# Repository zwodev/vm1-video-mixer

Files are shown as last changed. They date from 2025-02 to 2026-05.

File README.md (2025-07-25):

# VM-1 / The Video Mixer for Everyone

The VM-1 is an open-source hardware project for live mixing of videos, camera images and generative graphics. It is based on the widely used and affordable Raspberry Pi (5) platform, allowing creative media projects of all sorts.

Learn more about the VM-1 on our website: [VM-1 Website](https://vm-1.com)

## 🚀 Quick Start

You want to build your very own VM-1?! Awesome! This is how you do it:

### 1. Order the Parts
You're lucky! We've prepared a shopping list for you. This is a link to the shopping cart at BerryBase (Berlin, Germany). You don't have to buy the parts there and this is no affiliate link. It's just for your convenience!
This list includes everything you need. If you already own some parts, just delete them from the cart.

[Shopping List](https://www.berrybase.de/loadBasket/sqdnehV_owC)

### 2. Print your Case
Don't worry, you do not have wildly connect all the parts. We've prepared a neat little housing for your VM-1. You just have to print it on your own, your friend's or your makerspace's 3D-printer. If you have trouble getting your case printed, don't worry and drop us a line.

[3D Printing Files](#)

### 3. Download VM-1 image and flash your SD card
TODO

### 4. Assemble the VM-1
TODO

### 5. First Steps
TODO

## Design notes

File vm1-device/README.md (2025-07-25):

# VM-1 Controller

`arduino` - firmware

`kicad`- pcb

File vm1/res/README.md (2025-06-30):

# Enable autostart of VM1 and LocalSend

1) Check if directory `~/.config/systemd/user/` exists. If not, create it.
2) Copy `vm1.service` and `localsend.service` to `~/.config/systemd/user/`
3) Enable vm1.service:

```
$ systemctl --user enable localsend.service
$ systemctl --user enable vm1.service
$ systemctl --user daemon-reload
```

4) Reboot Raspberry Pi

# Enable external antenna (on Compute Module only)

1) Add `dtparam=ant2` to `/boot/firmware/config.txt`
2) disable power management for wifi adapter with systemd on system level:

```
sudo nano /etc/systemd/system/wifi-power-save-off.service
```

content:

```
[Unit]
Description=Disable WiFi Power Saving
After=network.target

[Service]
Type=oneshot
ExecStart=/sbin/iwconfig wlan0 power off
RemainAfterExit=true

[Install]
WantedBy=multi-user.target

```

enable it with:

```
sudo systemctl daemon-reexec 
sudo systemctl enable wifi-power-save-off.service
sudo systemctl start wifi-power-save-off.service   # or reboot
```

3) Reboot Raspberry Pi

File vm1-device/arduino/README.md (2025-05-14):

# VM-1 Controller

## Installation of existing binaries

~~On the Raspberry Pi Pico (V1), press and hold the `bootsel` button while plugging in into your USB-Port. It will appear as a removable disk. Drag and Drop the file `bin/VM1_Keyboard.ino.uf2` onto it. The Pi Pico will reboot and show up as a keyboard on your computer. You can then use it with your VM-1.~~

--> t.b.a.

## Assignments

### Buttons
* The controller acts simply as a HID Keyboard
* left-most button is `KEY_LEFT_SHIFT`
* two buttons at the top-right are `KEY_ARROW_LEFT` and `KEY_ARROW_RIGHT`
* the 8x3 button matrix is:
	* `q` `w` `e` `r` `t` `y` `u` `i`
	* `a` `s` `d` `f` `g` `h` `j` `k`
	* `z` `x` `c` `v` `b` `n` `m` `,`

### Rotary Encoder
* Acts as `ARROW_DOWN` (turn CW) and `ARROW_UP` (turn CCW)

### LEDs

* The four LEDs blink in a row. 
* ~~ You can change them with *Serial Commands*:~~
	* `0` - start the running animation (default)
	* `1` - turn on LED 1
	* `2` - turn on LED 2
	* `3` - turn on LED 3
	* `4` - turn on LED 4

## Working on the project

If you want to extend the VM-1 keyboard, you can use that with the source-code found in the `VM1_Keyboard`-folder. We use the PiPico board library by [Earle Philhower](https://github.com/earlephilhower/arduino-pico?tab=readme-ov-file#installation) because the implementation of the HID-Keyboard worked better for us. Please follow the installation instructions in the link (adding the link to the board-library in the Arduino-Settings). 

#### Used Libraries

In Arduino IDE, choose `Raspberry Pi Pico` (*not the Arduino Mbed, but the one mentioned above!*) as your Board. The following libraries are used:

* ~~[https://github.com/gbr1/rp2040-encoder-library](https://github.com/gbr1/rp2040-encoder-library)~~
	* this library gets in conflict with the Adafruit NeoPixels library. 

# Installing Arduino CLI on your Raspberry Pi

I attached the PiPico (aka the VM-1 Keyboard) to the Raspberry Pi (aka the VM-1). It shall be programmed directly from there.

The PiPico shows up as serial device under `/dev/ttyACM0`

In the home directory:

```
curl -fsSL https://raw.githubusercontent.com/arduino/arduino-cli/master/install.sh | sh
export PATH=$PATH:$HOME/bin

arduino-cli config init
arduino-cli config set board_manager.additional_urls https://github.com/earlephilhower/arduino-pico/releases/download/global/package_rp2040_index.json
arduino-cli core update-index
arduino-cli core install rp2040:rp2040

```

In the arduino project directory (`/home/vm1/Documents/coding/vm1-video-mixer/vm1-controller/arduino/VM1_Keyboard`) you can compile it with

arduino-cli compile --fqbn rp2040:rp2040:rpipico --verbose --build-path ./build .

### ~~not needed (hopefully) BEGIN~~
~~upload the file to pi pico~~
~~press bootsel button and plug the pico in~~
~~(mount if needed)~~
~~mkdir -p ~/pico_mount~~
~~lsblk~~
~~sudo mount /dev/sda1 ~/pico_mount~~

~~sudo cp your_program.uf2 ~/pico_mount/~~
### ~~not needed END~~

# get a serial monitor

sudo apt-get install minicom

minicom -b 115200 -o -D /dev/ttyACM0

# Install Neopixel library

arduino-cli lib install "Adafruit NeoPixel"

# Install MessagePack

git clone https://github.com/hideakitai/MsgPack.git
git clone https://github.com/hideakitai/DebugLog.git
git clone https://github.com/hideakitai/ArxTypeTraits.git
git clone https://github.com/hideakitai/ArxContainer.git

# install Rotary Encoder Library

git clone https://github.com/tobiglaser/RP2040-Encoder.git

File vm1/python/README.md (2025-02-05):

# HOWTO

## Install dependencies on Raspberry Pi 4/5
```
# gstreamer
sudo apt install libgstreamer1.0-dev libgstreamer-plugins-base1.0-dev libgstreamer-plugins-bad1.0-dev gstreamer1.0-plugins-ugly gstreamer1.0-tools gstreamer1.0-gl gstreamer1.0-gtk3 python3-gst-1.0

```

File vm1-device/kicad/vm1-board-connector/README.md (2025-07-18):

# VM1 Board Connector

Connects the VM1-Device PCB with the Raspberry Pi CM5 IO Board PCB.

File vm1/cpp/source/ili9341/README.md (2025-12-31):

# ILI9341 Display Driver

This directory contains the driver for the 2.8-inch ILI9341 SPI LCD display.

## Pin Connections

The driver uses the following GPIO pins (BCM numbering):

- **CS (Chip Select)**: GPIO 7
- **RST (Reset)**: GPIO 17  
- **RS/DC (Register Select/Data Command)**: GPIO 22
- **LED (Backlight)**: GPIO 18
- **MOSI**: SPI0 MOSI (GPIO 10)
- **SCK**: SPI0 SCK (GPIO 11)
- **MISO**: SPI0 MISO (GPIO 9) - optional, not used for display writes

## Hardware Setup

1. Connect the display to the Raspberry Pi according to the pin mapping above
2. The display uses SPI bus 0 (same as OLED, but different CS pin)
3. Power: Connect VCC to 5V and GND to ground

## Usage

The `ILI9341Controller` class provides a high-level interface similar to `OledController`:

```cpp
#include "ILI9341Controller.h"

ILI9341Controller display;
display.setStbRenderer(stbRenderer);  // Optional: for rendering UI
display.start();  // Start the display thread
// ... use display ...
display.stop();   // Stop when done
```

## Display Specifications

- **Resolution**: 240x320 pixels
- **Color Format**: RGB565 (16-bit color)
- **SPI Mode**: Mode 0
- **SPI Speed**: 32 MHz

## Notes

- The display driver uses **weak linkage** to avoid conflicts with the OLED driver
- Both displays can coexist on the same SPI bus using different CS pins
- The display will NOT be used as the main system display - it's a pure SPI device
- Touch functionality is not implemented (as requested)

## Integration

To use the ILI9341 display in your application, you can:

1. Create an instance of `ILI9341Controller`
2. Optionally connect it to a `StbRenderer` for UI rendering
3. Call `start()` to begin displaying content
4. The display will automatically update from the renderer

Example integration in `VM1Application`:

```cpp
ILI9341Controller m_ili9341Display;

// In initialization:
m_ili9341Display.setStbRenderer(&m_stbRenderer);
m_ili9341Display.start();
```

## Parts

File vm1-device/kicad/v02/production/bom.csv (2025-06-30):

Designator | Footprint | Quantity | Value | LCSC Part #
3.3V1 | TestPoint_Pad_2.0x2.0mm | 1 | 3.3V
ADC_0 | TestPoint_Pad_2.0x2.0mm | 1 | ADC_0
ADC_1 | TestPoint_Pad_2.0x2.0mm | 1 | ADC_1
ADC_2 | TestPoint_Pad_2.0x2.0mm | 1 | ADC_2
ADC_3 | TestPoint_Pad_2.0x2.0mm | 1 | ADC_3
C1, C2, C3, C4 | 0402 | 4 | 10n | C15195
C10, C23, C24, C8 | 0402 | 4 | 1u | C52923
C11, C12, C13, C14, C15, C16, C22, C25, C5, C6, C7, C9 | 0402 | 12 | 100n
C17, C18 | 0402 | 2 | 15p
C19, C20, C21 | CP_EIA-3216-10_Kemet-I | 3 | 10u | C7171
D1, D10, D11, D12, D13, D14, D15, D16, D17, D18, D19, D2, D20, D21, D22, D23, D24, D25, D26, D27, D28, D29, D3, D30, D31, D32, D33, D4, D5, D6, D7, D8, D9 | LED_WS2812B-2020_PLCC4_2.0x2.0mm | 33 | WS2812B-2020
GND1 | TestPoint_Pad_2.0x2.0mm | 1 | GND
H1, H2, H22, H3, H4, H5 | MountingHole_3.2mm_M3 | 6 | MountingHole
R1, R10, R11, R18, R2, R20, R21, R22, R3, R4, R5, R6, R7, R8, R9 | 0402 | 15 | 10k | C25744
R12, R13, R23 | 0402 | 3 | 27
R15, R16 | 0402 | 2 | 1k
R17, R19 | 0402 | 2 | 5.1k
U1, U10, U11, U12, U13, U14, U15, U16, U17, U18, U19, U2, U20, U21, U22, U23, U24, U25, U26, U28, U3, U4, U5, U6, U7, U8, U9 | D_SOD-123 | 27 | 1N4148W_C81598 | C81598
U27 | SOT-353_L2.1-W1.3-P0.65-LS2.3-BR | 1 | 74LVC1G17GW,125_C426705 | C426705
U29 | SOT-223-3_L6.5-W3.4-P2.30-LS7.0-BR | 1 | AMS1117-3_3 | C6186
U30 | RP2040-QFN-56 | 1 | RP2040 | C2040
U31 | USB-C-SMD_TYPE-C-6PIN-2MD-073 | 1 | TYPE-C_16PIN_2MD(073) | C2765186
U32 | SOIC-8_L5.3-W5.3-P1.27-LS8.0-BL | 1 | W25Q128JVSIQTR | C97521
U33, U34 | SW-SMD_L3.9-W3.0-P4.45 | 2 | TS-1088-AR02016 | C720477
X2 | CRYSTAL-SMD_4P-L3.2-W2.5-BL | 1 | ABM8-272-T3_C20625731 | C20625731

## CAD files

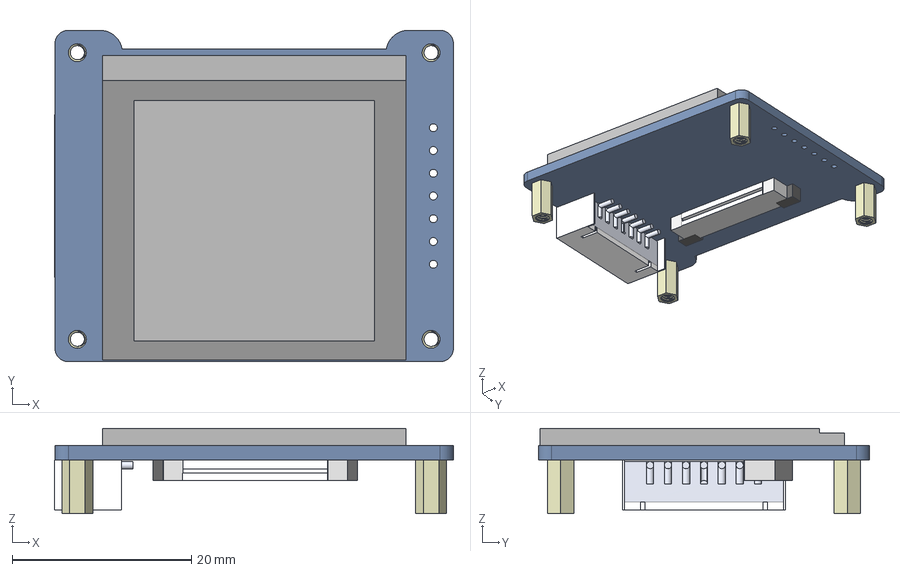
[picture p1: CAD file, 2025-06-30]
vm1-device/kicad/v02/3dmodels/1_5inch-rgb-oled-module_asm-1110.stp
44.5 x 37.0 x 9.50 mm
1_5INCH-RGB-OLED
1_5INCH_OLED_RGB_PCBA
M2XH6_COPPER-POST x 4

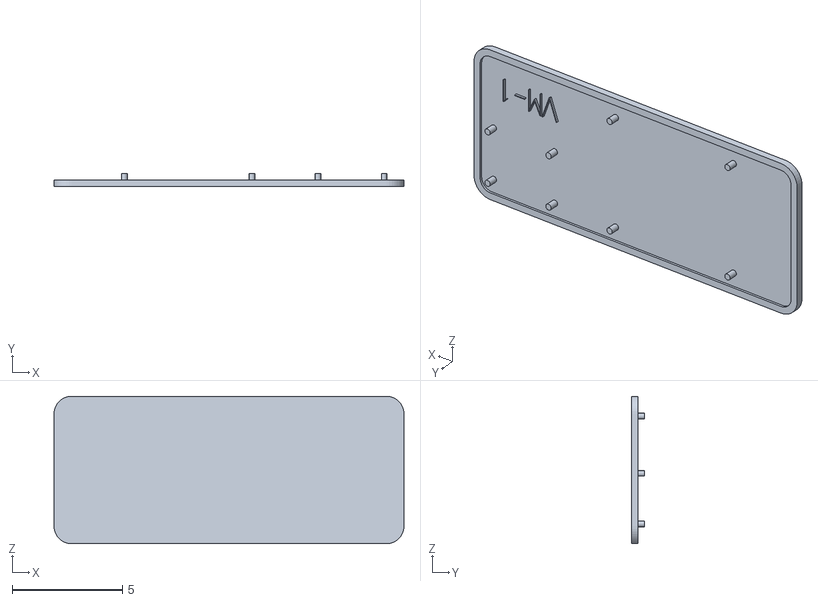
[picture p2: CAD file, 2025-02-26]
3d-print/prototype/baseplate.stl
15.9 x 0.6 x 6.70

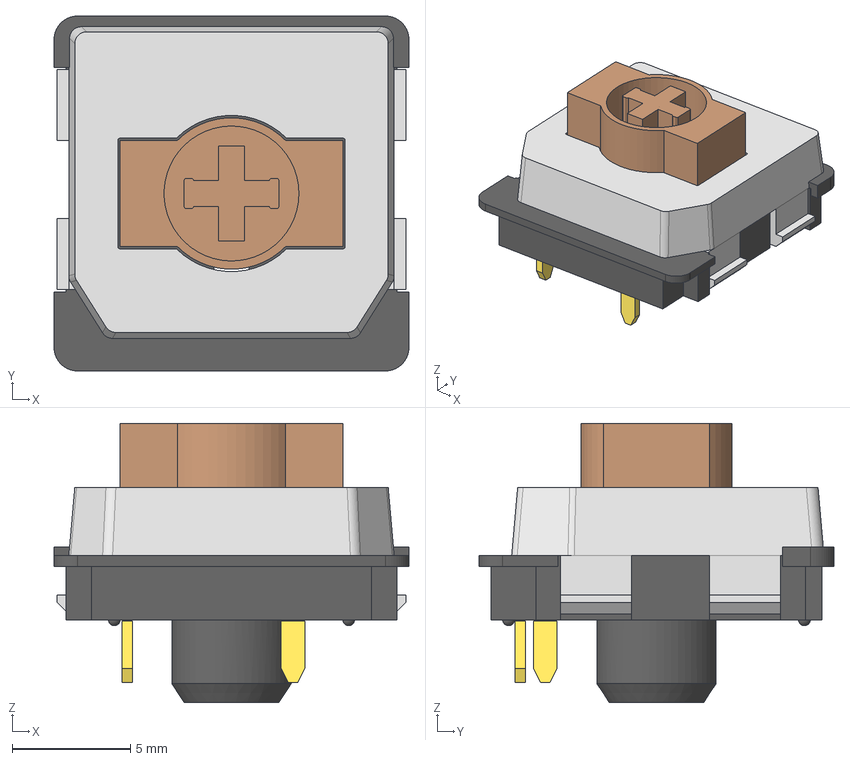
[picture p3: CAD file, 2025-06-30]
vm1-device/kicad/v02/3dmodels/ks33.step
15.0 x 15.0 x 11.8 mm
f0684a6a-028c-11ee-ae0e-34c93d8226b1_part
f06a1f0c-028c-11ee-ae0e-34c93d8226b1_part
f1cc5b76-028c-11ee-ae0e-34c93d8226b1_part
f1cc5d06-028c-11ee-ae0e-34c93d8226b1_part
f1cc5d92-028c-11ee-ae0e-34c93d8226b1_part

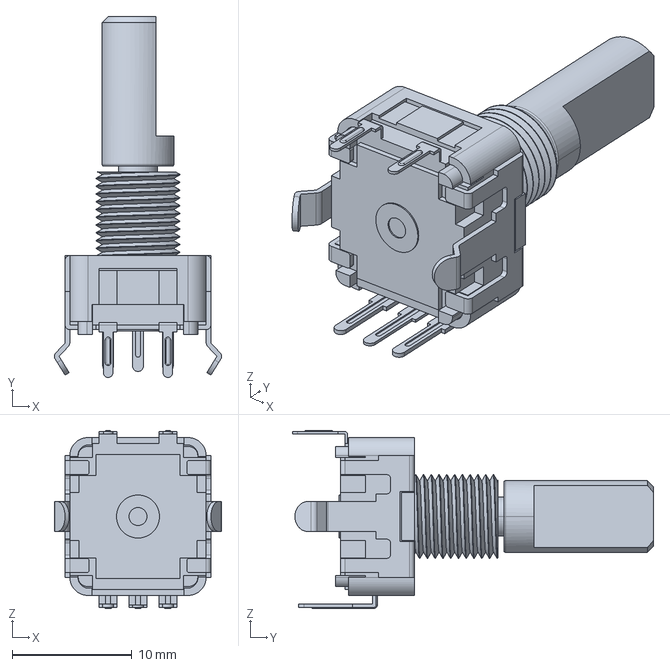
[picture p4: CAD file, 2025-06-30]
vm1-device/kicad/v02/3dmodels/7377754.stp
14.0 x 30.2 x 14.9 mm

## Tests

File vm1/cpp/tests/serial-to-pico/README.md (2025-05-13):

# Test for sending a MessagePack message

...which will be received by [this Arduino script](https://github.com/zwodev/vm1-video-mixer/tree/master/vm1-controller/arduino/tests/20250507-msgpck-receive-and-neopixels-test).

## Dependencies

```
$ sudo apt install libmsgpack-dev
```
## Compile and Run
```
$ mkdir builddir
$ meson setup builddir

$ meson compile -C builddir
$ ./builddir/serial-test
```

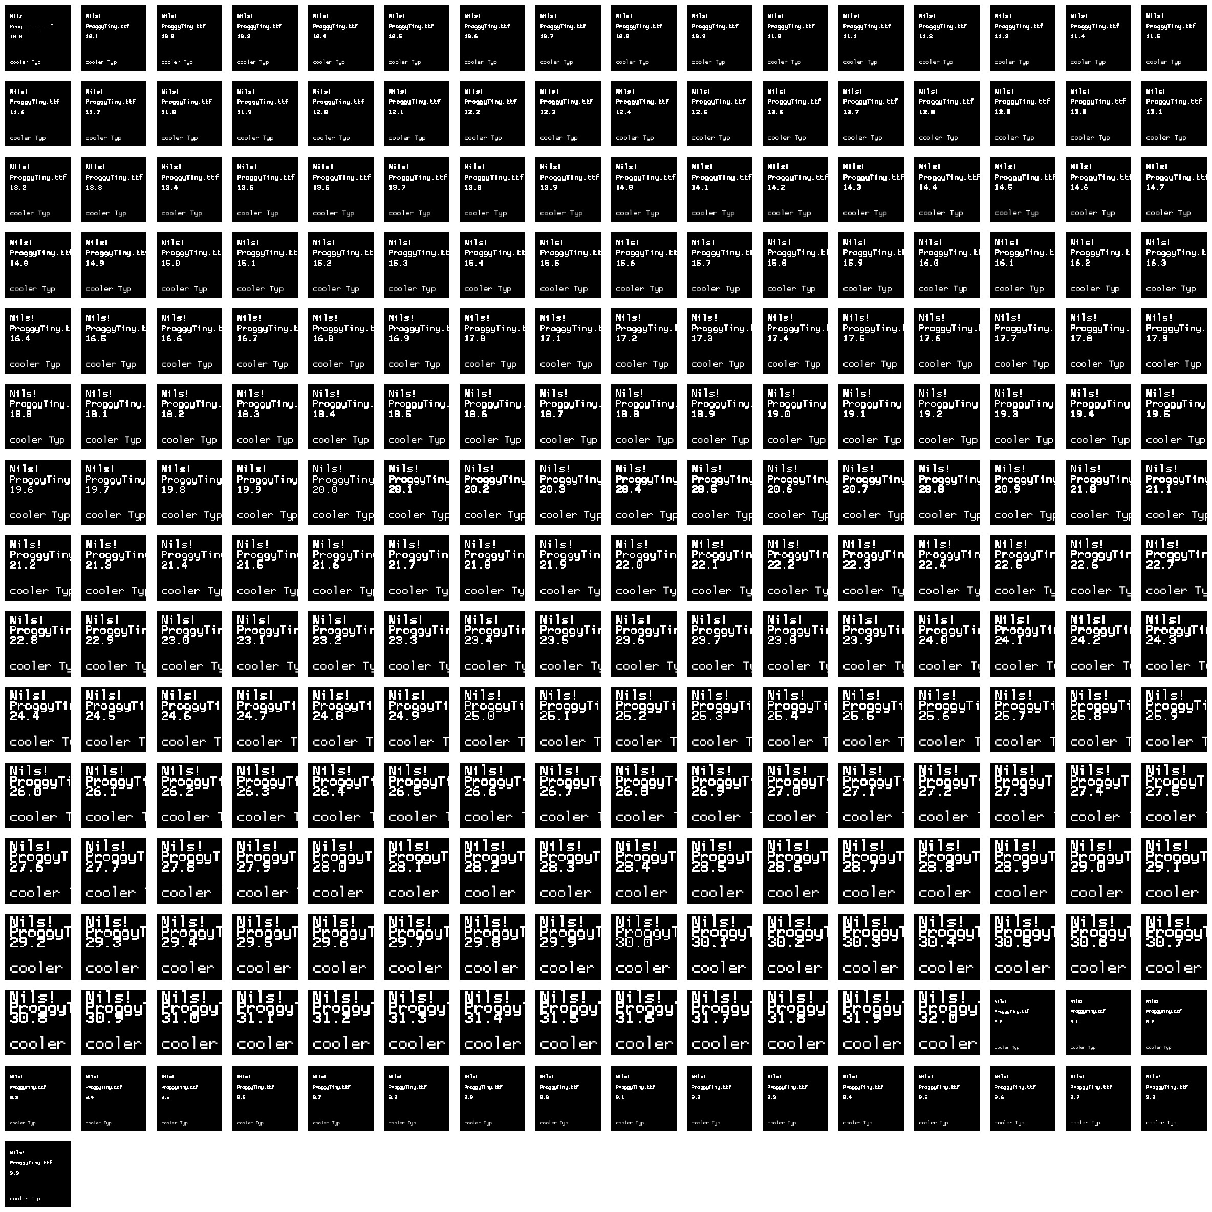
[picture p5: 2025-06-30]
vm1/cpp/tests/stb-test/rendered-tiles/ProggyTiny.png

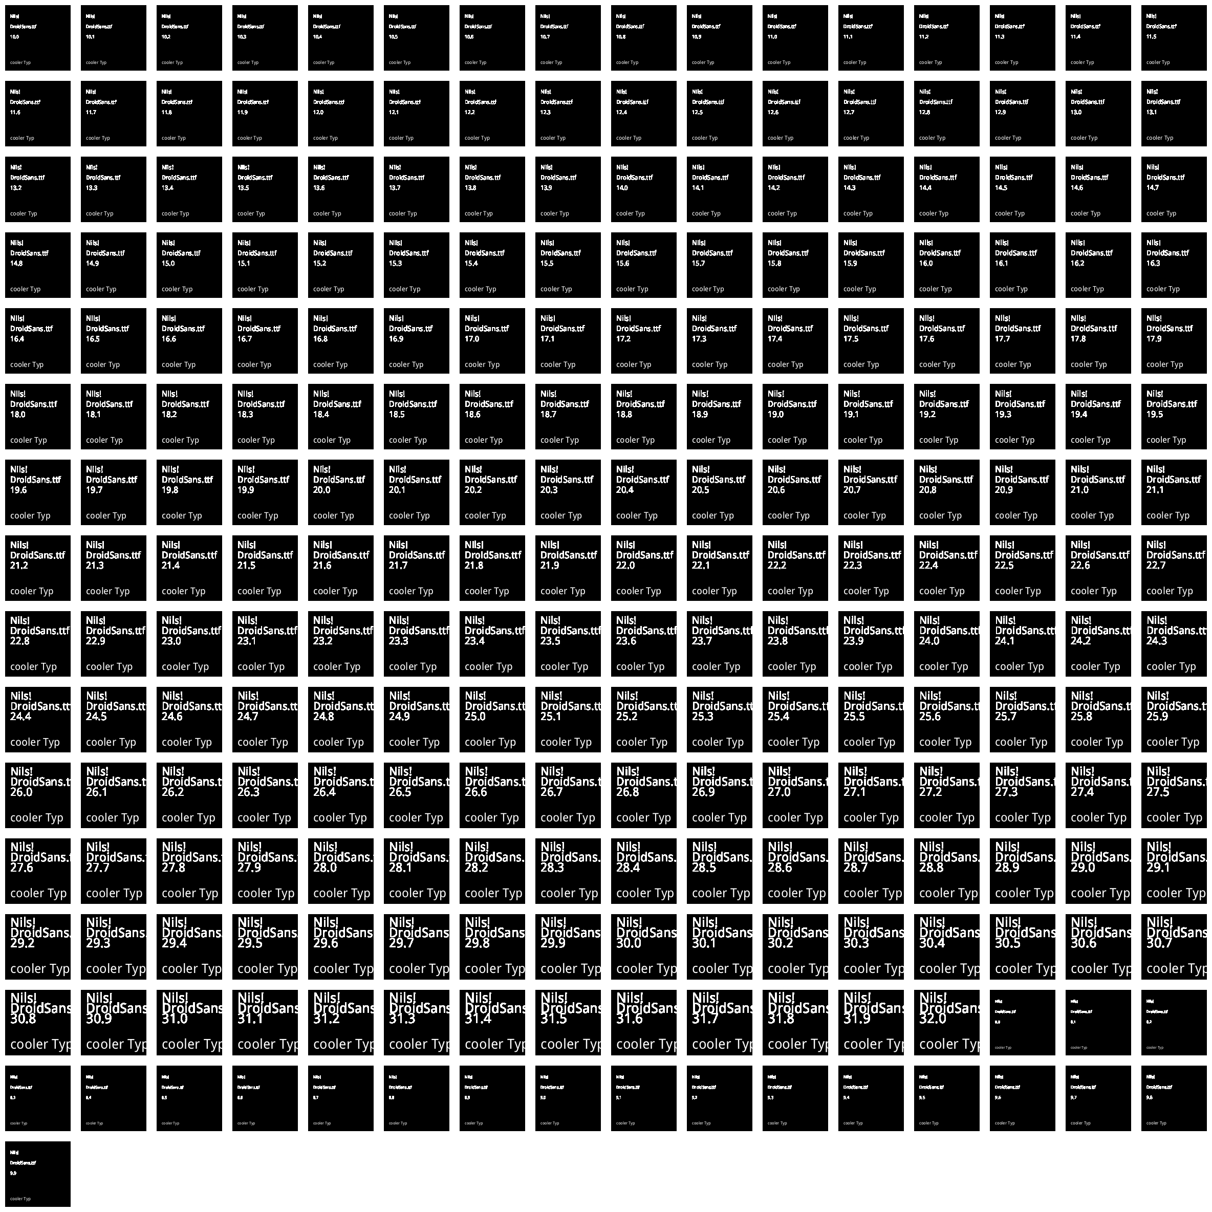
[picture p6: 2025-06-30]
vm1/cpp/tests/stb-test/rendered-tiles/DroidSans.png

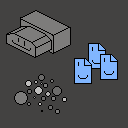
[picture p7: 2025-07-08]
vm1/cpp/tests/stb-test/resources/source-file.png

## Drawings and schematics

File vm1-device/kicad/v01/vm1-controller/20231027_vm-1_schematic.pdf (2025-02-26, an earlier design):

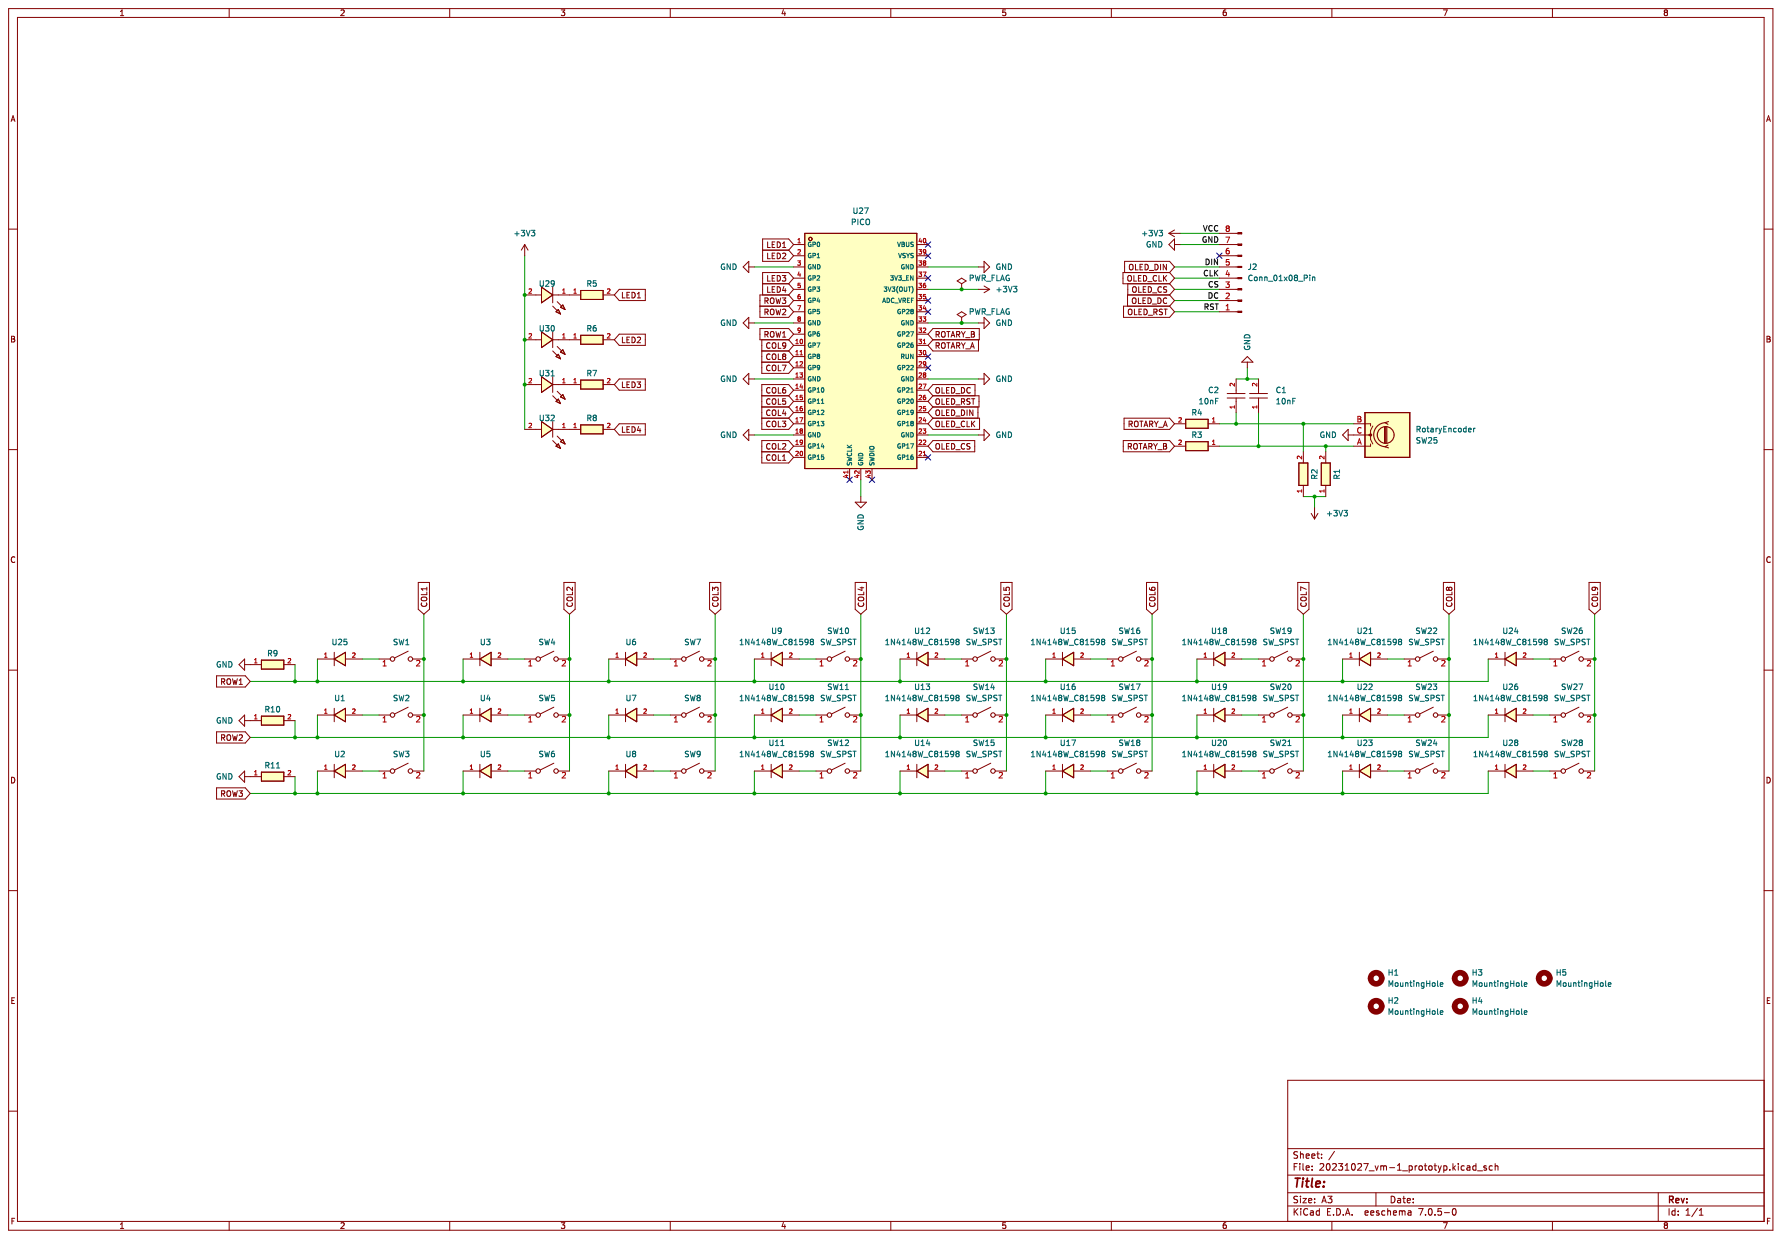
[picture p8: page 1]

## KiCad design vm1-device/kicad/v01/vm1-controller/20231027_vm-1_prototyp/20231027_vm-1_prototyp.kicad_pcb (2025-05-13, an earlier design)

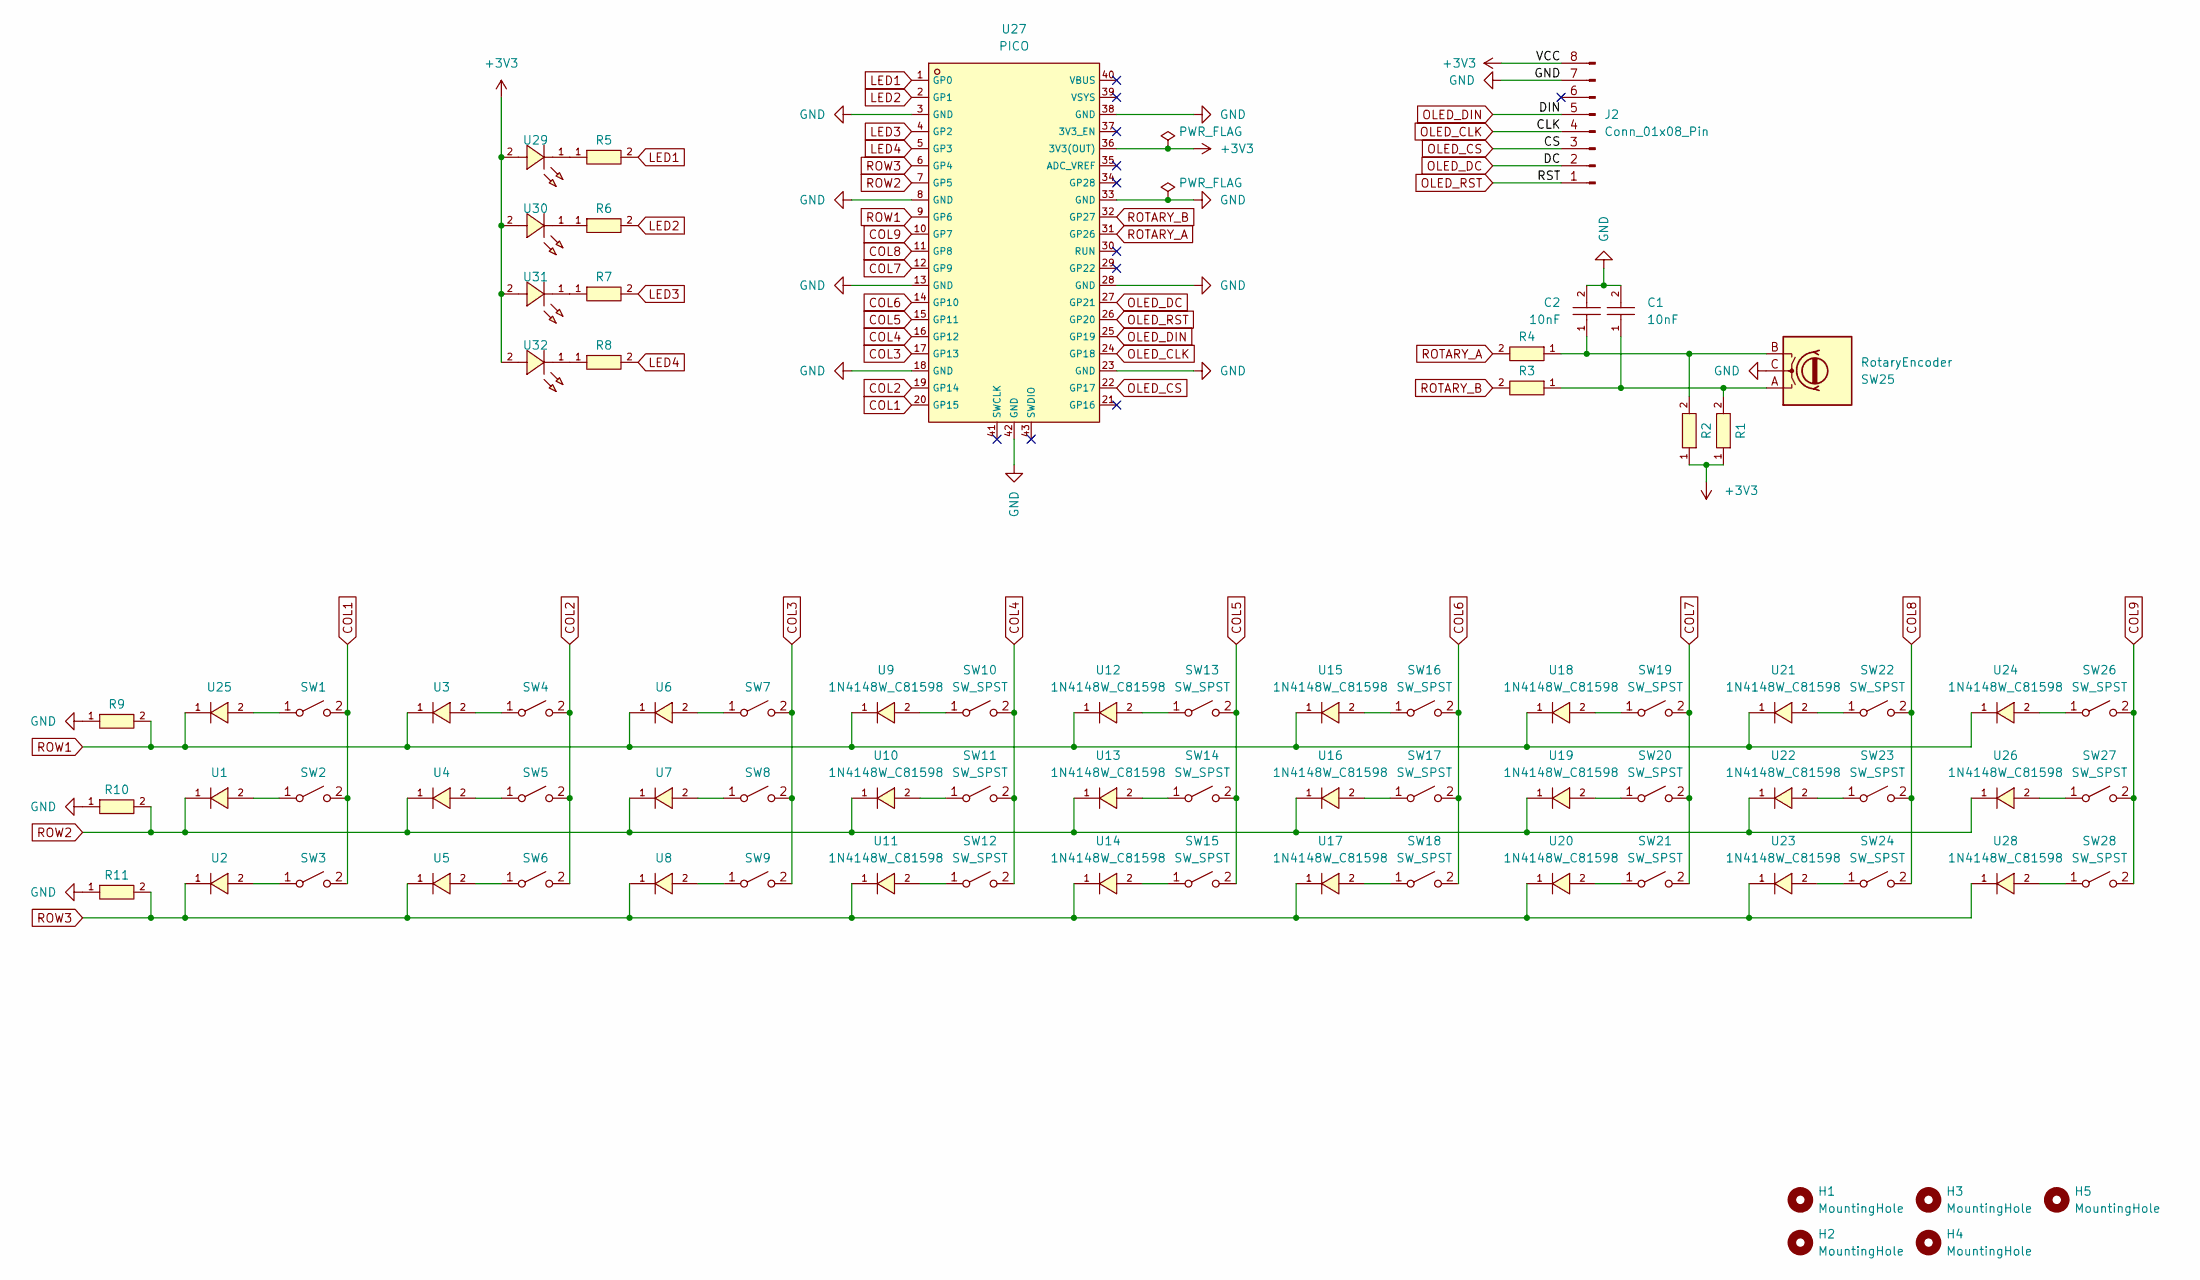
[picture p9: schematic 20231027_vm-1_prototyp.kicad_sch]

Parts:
C1, C2: 10nF; C0402; LCSC C15195
H1, H2, H3, H4, H5: MountingHole; MountingHole_3.2mm_M3
J2: Conn_01x08_Pin; Waveshare OLED 1.5in
R1, R2, R9, R10, R11: 0402WGF1002TCE; R0402; LCSC C25744
R3, R4: 0402WGF1002TCE 10k; R0402; LCSC C25744
R5, R6, R7, R8: 0402WGF1000TCE; R0402; LCSC C25076
SW1, SW2, SW3, SW4, SW5, SW6, SW7, SW8, SW9, SW10, SW11, SW12, SW13, SW14, SW15, SW16, SW17, SW18, SW19, SW20, SW21, SW22, SW23, SW24, SW26, SW27, SW28: SW_SPST; SW_Cherry_MX_PCB_1.00u
SW25: RotaryEncoder; RotaryEncoder_Bourns_Vertical_PEC12R-3xxxF-Nxxxx
U1, U2, U3, U4, U5, U6, U7, U8, U9, U10, U11, U12, U13, U14, U15, U16, U17, U18, U19, U20, U21, U22, U23, U24, U25, U26, U28: 1N4148W_C81598; SOD-123F_L2.7-W1.6-LS3.8-RD; LCSC C81598
U27: PICO; COMM-SMD_L51.0-W21.0-P2.54_SC0916; LCSC C7203002
U29, U30, U31, U32: 95-21SURC_S530-A3_TR10; LED-SMD_L2.1-W2.0-RD; LCSC C2936535

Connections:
+3V3: J2.8, R1.1, R2.1, U27.36 (3V3(OUT)), U29.2 (A), U30.2 (A), U31.2 (A), U32.2 (A)
COL1: SW1.2 (B), SW2.2 (B), SW3.2 (B), U27.20 (GP15)
COL2: SW4.2 (B), SW5.2 (B), SW6.2 (B), U27.19 (GP14)
COL3: SW7.2 (B), SW8.2 (B), SW9.2 (B), U27.17 (GP13)
COL4: SW10.2 (B), SW11.2 (B), SW12.2 (B), U27.16 (GP12)
COL5: SW13.2 (B), SW14.2 (B), SW15.2 (B), U27.15 (GP11)
COL6: SW16.2 (B), SW17.2 (B), SW18.2 (B), U27.14 (GP10)
COL7: SW19.2 (B), SW20.2 (B), SW21.2 (B), U27.12 (GP9)
COL8: SW22.2 (B), SW23.2 (B), SW24.2 (B), U27.11 (GP8)
COL9: SW26.2 (B), SW27.2 (B), SW28.2 (B), U27.10 (GP7)
GND: C1.2, C2.2, J2.7, R9.1, R10.1, R11.1, SW25.C, U27.3 (GND), U27.8 (GND), U27.13 (GND), U27.18 (GND), U27.23 (GND), U27.28 (GND), U27.33 (GND), U27.38 (GND), U27.42 (GND)
LED1: R5.2, U27.1 (GP0)
LED2: R6.2, U27.2 (GP1)
LED3: R7.2, U27.4 (GP2)
LED4: R8.2, U27.5 (GP3)
unnamed: C1.1, R1.2, R3.1, SW25.A
unnamed: C2.1, R2.2, R4.1, SW25.B
unnamed: SW1.1 (A), U25.2 (A)
unnamed: SW2.1 (A), U1.2 (A)
unnamed: SW3.1 (A), U2.2 (A)
unnamed: SW4.1 (A), U3.2 (A)
unnamed: SW5.1 (A), U4.2 (A)
unnamed: SW6.1 (A), U5.2 (A)
unnamed: SW7.1 (A), U6.2 (A)
unnamed: SW8.1 (A), U7.2 (A)
unnamed: SW9.1 (A), U8.2 (A)
unnamed: SW10.1 (A), U9.2 (A)
unnamed: SW11.1 (A), U10.2 (A)
unnamed: SW12.1 (A), U11.2 (A)
unnamed: SW13.1 (A), U12.2 (A)
unnamed: SW14.1 (A), U13.2 (A)
unnamed: SW15.1 (A), U14.2 (A)
unnamed: SW16.1 (A), U15.2 (A)
unnamed: SW17.1 (A), U16.2 (A)
unnamed: SW18.1 (A), U17.2 (A)
unnamed: SW19.1 (A), U18.2 (A)
unnamed: SW20.1 (A), U19.2 (A)
unnamed: SW21.1 (A), U20.2 (A)
unnamed: SW22.1 (A), U21.2 (A)
unnamed: SW23.1 (A), U22.2 (A)
unnamed: SW24.1 (A), U23.2 (A)
unnamed: SW26.1 (A), U24.2 (A)
unnamed: SW27.1 (A), U26.2 (A)
unnamed: SW28.1 (A), U28.2 (A)
unnamed: R5.1, U29.1 (K)
unnamed: R6.1, U30.1 (K)
unnamed: R7.1, U31.1 (K)
unnamed: R8.1, U32.1 (K)
OLED_CLK: J2.4, U27.24 (GP18)
OLED_CS: J2.3, U27.22 (GP17)
OLED_DC: J2.2, U27.27 (GP21)
OLED_DIN: J2.5, U27.25 (GP19)
OLED_RST: J2.1, U27.26 (GP20)
ROTARY_A: R4.2, U27.31 (GP26)
ROTARY_B: R3.2, U27.32 (GP27)
ROW1: R9.2, U3.1 (K), U6.1 (K), U9.1 (K), U12.1 (K), U15.1 (K), U18.1 (K), U21.1 (K), U24.1 (K), U25.1 (K), U27.9 (GP6)
ROW2: R10.2, U1.1 (K), U4.1 (K), U7.1 (K), U10.1 (K), U13.1 (K), U16.1 (K), U19.1 (K), U22.1 (K), U26.1 (K), U27.7 (GP5)
ROW3: R11.2, U2.1 (K), U5.1 (K), U8.1 (K), U11.1 (K), U14.1 (K), U17.1 (K), U20.1 (K), U23.1 (K), U27.6 (GP4), U28.1 (K)

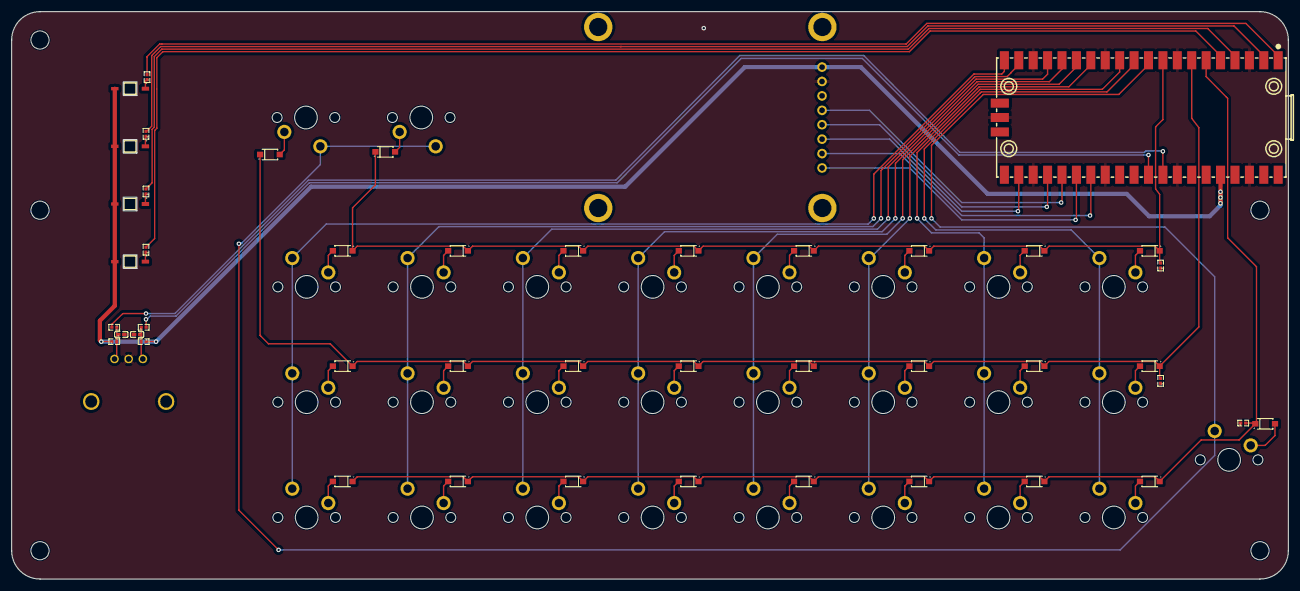
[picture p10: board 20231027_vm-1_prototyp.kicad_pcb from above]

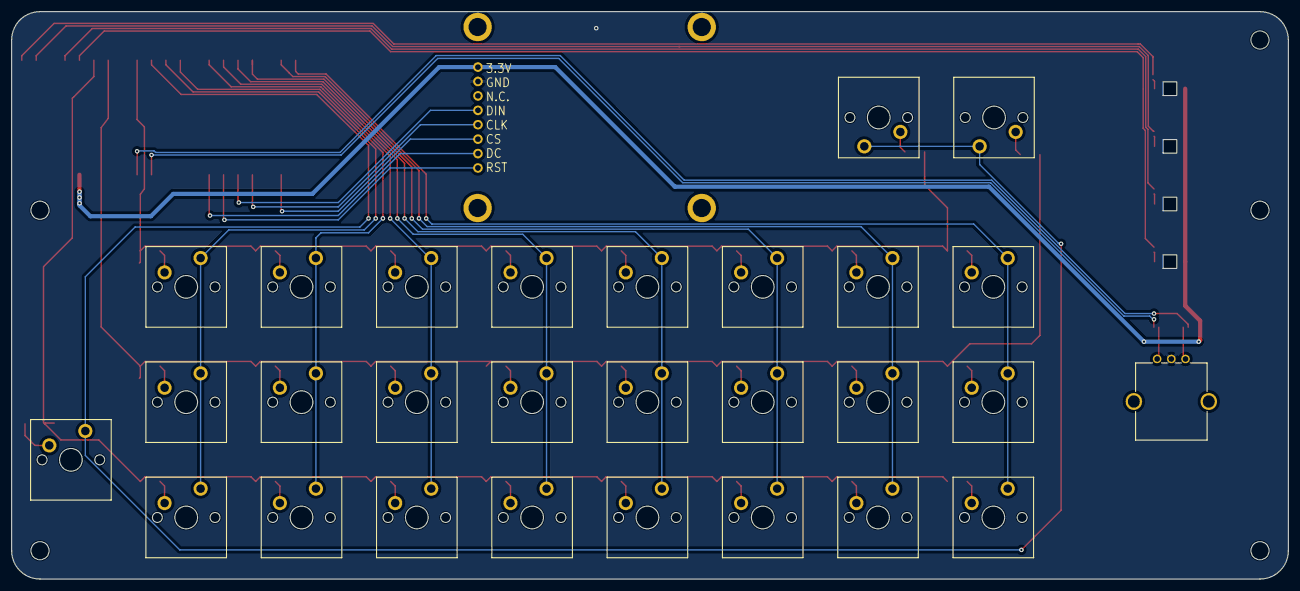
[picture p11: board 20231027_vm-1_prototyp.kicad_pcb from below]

Board: 2 copper layers, 225.0 x 100.0 mm, 79 parts (29 on the bottom side), 58 nets.

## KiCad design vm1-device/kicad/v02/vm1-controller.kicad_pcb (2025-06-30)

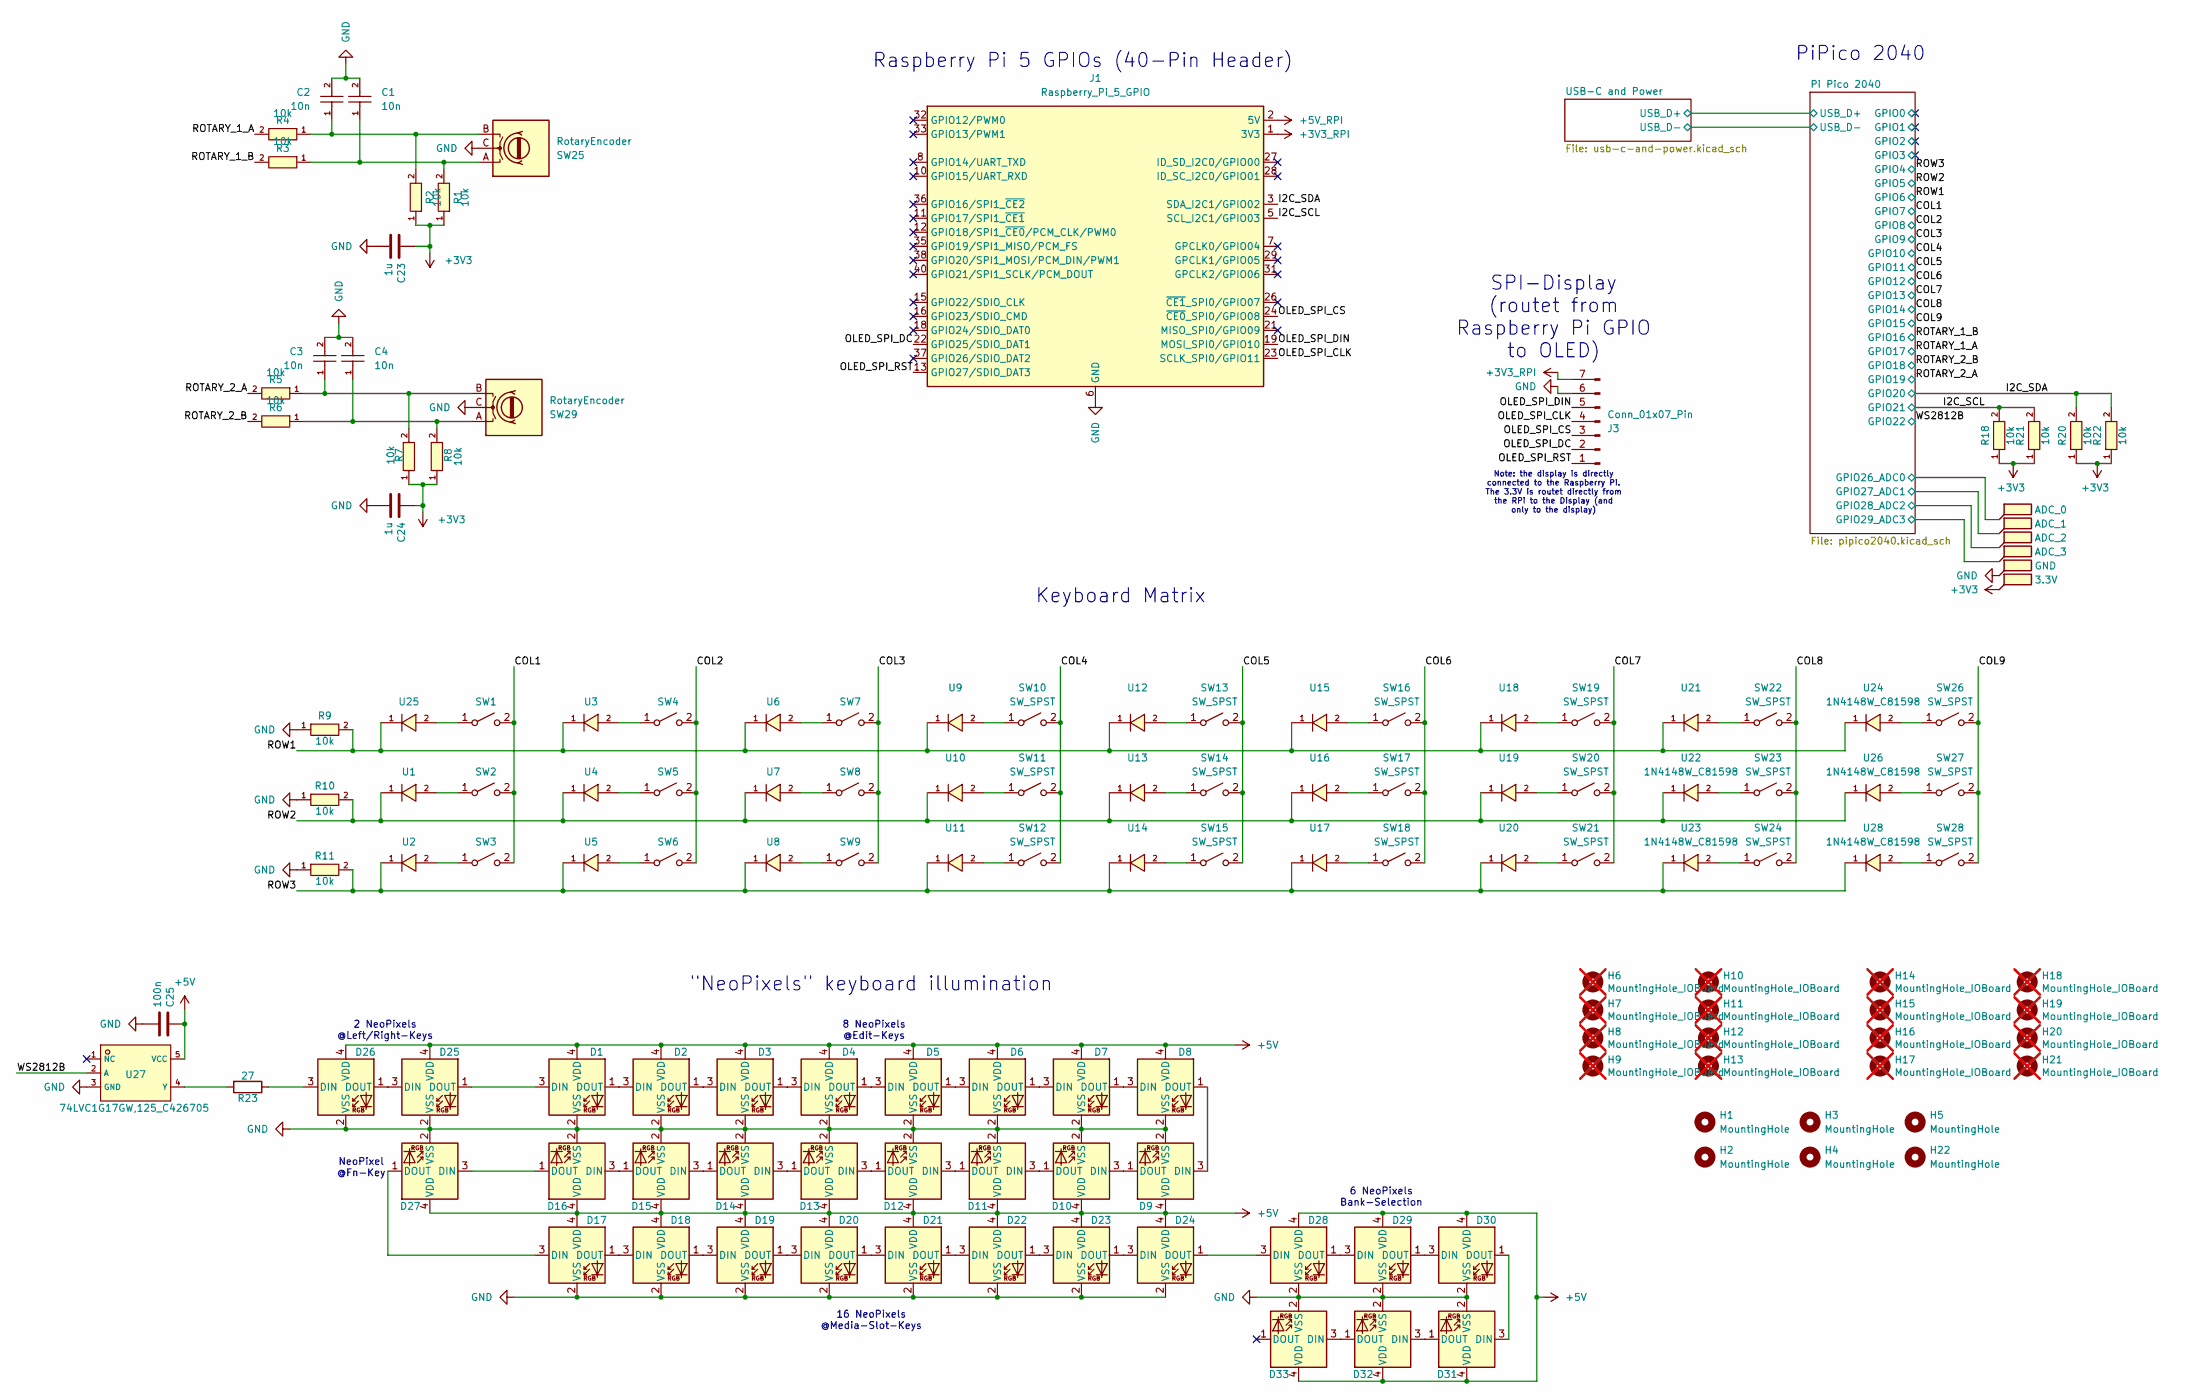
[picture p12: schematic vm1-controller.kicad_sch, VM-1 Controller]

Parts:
3.3V1: 3.3V; TestPoint_Pad_2.0x2.0mm
ADC_0: ADC_0; TestPoint_Pad_2.0x2.0mm
ADC_1: ADC_1; TestPoint_Pad_2.0x2.0mm
ADC_2: ADC_2; TestPoint_Pad_2.0x2.0mm
ADC_3: ADC_3; TestPoint_Pad_2.0x2.0mm
C1, C2, C3, C4: 10n; C_0402_1005Metric; LCSC C15195
C23, C24: 1u; C_0402_1005Metric; LCSC C52923
C25: 100n; C_0402_1005Metric
D1, D2, D3, D4, D5, D6, D7, D8, D9, D10, D11, D12, D13, D14, D15, D16, D17, D18, D19, D20, D21, D22, D23, D24, D25, D26, D27, D28, D29, D30, D31, D32, D33: WS2812B-2020; LED_WS2812B-2020_PLCC4_2.0x2.0mm
GND1: GND; TestPoint_Pad_2.0x2.0mm
H1, H2, H3, H4, H5, H22: MountingHole; MountingHole_3.2mm_M3
H6, H7, H8, H9, H10, H11, H12, H13, H14, H15, H16, H17, H18, H19, H20, H21: MountingHole_IOBoard; MountingHole_2.5mm; Part Description M2.5 mounting hole; not fitted
J1: Raspberry_Pi_5_GPIO; PinSocket_2x20_P2.54mm_Vertical
J3: Conn_01x07_Pin; Waveshare-OLED-RGB-1.5in
R1, R2, R3, R4, R5, R6, R7, R8, R9, R10, R11, R18, R20, R21, R22: 10k; R_0402_1005Metric; LCSC C25744
R23: 27; R_0402_1005Metric
SW1, SW2, SW3, SW4, SW5, SW6, SW7, SW8, SW9, SW10, SW11, SW12, SW13, SW14, SW15, SW16, SW17, SW18, SW19, SW20, SW21, SW22, SW23, SW24, SW26, SW27, SW28: SW_SPST; SW_Gateron_LowProfile_THT
SW25, SW29: RotaryEncoder; RotaryEncoder_Bourns_Vertical_PEC12R-3x17F-Nxxxx
U1, U2, U3, U4, U5, U6, U7, U8, U9, U10, U11, U12, U13, U14, U15, U16, U17, U18, U19, U20, U21, U22, U23, U24, U25, U26, U28: 1N4148W_C81598; D_SOD-123; LCSC C81598
U27: 74LVC1G17GW,125_C426705; SOT-353_L2.1-W1.3-P0.65-LS2.3-BR; LCSC C426705

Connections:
+3V3: 3.3V1.1, C23.1, C24.1, R1.1, R2.1, R7.1, R8.1, R18.1, R20.1, R21.1, R22.1; also elsewhere on the board
+3V3_RPI: J1.1 (3V3), J1.17 (3V3), J3.7
+5V: C25.1, D1.4 (VDD), D2.4 (VDD), D3.4 (VDD), D4.4 (VDD), D5.4 (VDD), D6.4 (VDD), D7.4 (VDD), D8.4 (VDD), D9.4 (VDD), D10.4 (VDD), D11.4 (VDD), D12.4 (VDD), D13.4 (VDD), D14.4 (VDD), D15.4 (VDD), D16.4 (VDD), D17.4 (VDD), D18.4 (VDD), D19.4 (VDD), D20.4 (VDD), D21.4 (VDD), D22.4 (VDD), D23.4 (VDD), D24.4 (VDD), D25.4 (VDD), D26.4 (VDD), D27.4 (VDD), D28.4 (VDD), D29.4 (VDD), D30.4 (VDD), D31.4 (VDD), D32.4 (VDD), D33.4 (VDD), U27.5 (VCC); also elsewhere on the board
+5V_RPI: J1.2 (5V), J1.4 (5V); also elsewhere on the board
/COL1: SW1.2 (B), SW2.2 (B), SW3.2 (B); also elsewhere on the board
/COL2: SW4.2 (B), SW5.2 (B), SW6.2 (B); also elsewhere on the board
/COL3: SW7.2 (B), SW8.2 (B), SW9.2 (B); also elsewhere on the board
/COL4: SW10.2 (B), SW11.2 (B), SW12.2 (B); also elsewhere on the board
/COL5: SW13.2 (B), SW14.2 (B), SW15.2 (B); also elsewhere on the board
/COL6: SW16.2 (B), SW17.2 (B), SW18.2 (B); also elsewhere on the board
/COL7: SW19.2 (B), SW20.2 (B), SW21.2 (B); also elsewhere on the board
/COL8: SW22.2 (B), SW23.2 (B), SW24.2 (B); also elsewhere on the board
/COL9: SW26.2 (B), SW27.2 (B), SW28.2 (B); also elsewhere on the board
/I2C_SCL: J1.5 (SCL_I2C1/GPIO03), R18.2, R21.2; also elsewhere on the board
/I2C_SDA: J1.3 (SDA_I2C1/GPIO02), R20.2, R22.2; also elsewhere on the board
/OLED_SPI_CLK: J1.23 (SCLK_SPI0/GPIO11), J3.4
/OLED_SPI_CS: J1.24 (~CE0_SPI0/GPIO08), J3.3
/OLED_SPI_DC: J1.22 (GPIO25/SDIO_DAT1), J3.2
/OLED_SPI_DIN: J1.19 (MOSI_SPI0/GPIO10), J3.5
/OLED_SPI_RST: J1.13 (GPIO27/SDIO_DAT3), J3.1
/Pi Pico 2040/GPIO26_ADC0: ADC_0.1; also elsewhere on the board
/Pi Pico 2040/GPIO27_ADC1: ADC_1.1; also elsewhere on the board
/Pi Pico 2040/GPIO28_ADC2: ADC_2.1; also elsewhere on the board
/Pi Pico 2040/GPIO29_ADC3: ADC_3.1; also elsewhere on the board
/ROTARY_1_A: R4.2; also elsewhere on the board
/ROTARY_1_B: R3.2; also elsewhere on the board
/ROTARY_2_A: R5.2; also elsewhere on the board
/ROTARY_2_B: R6.2; also elsewhere on the board
/ROW1: R9.2, U3.1 (K), U6.1 (K), U9.1 (K), U12.1 (K), U15.1 (K), U18.1 (K), U21.1 (K), U24.1 (K), U25.1 (K); also elsewhere on the board
/ROW2: R10.2, U1.1 (K), U4.1 (K), U7.1 (K), U10.1 (K), U13.1 (K), U16.1 (K), U19.1 (K), U22.1 (K), U26.1 (K); also elsewhere on the board
/ROW3: R11.2, U2.1 (K), U5.1 (K), U8.1 (K), U11.1 (K), U14.1 (K), U17.1 (K), U20.1 (K), U23.1 (K), U28.1 (K); also elsewhere on the board
/WS2812B: U27.2 (A); also elsewhere on the board
GND: C1.2, C2.2, C3.2, C4.2, C23.2, C24.2, C25.2, D1.2 (VSS), D2.2 (VSS), D3.2 (VSS), D4.2 (VSS), D5.2 (VSS), D6.2 (VSS), D7.2 (VSS), D8.2 (VSS), D9.2 (VSS), D10.2 (VSS), D11.2 (VSS), D12.2 (VSS), D13.2 (VSS), D14.2 (VSS), D15.2 (VSS), D16.2 (VSS), D17.2 (VSS), D18.2 (VSS), D19.2 (VSS), D20.2 (VSS), D21.2 (VSS), D22.2 (VSS), D23.2 (VSS), D24.2 (VSS), D25.2 (VSS), D26.2 (VSS), D27.2 (VSS), D28.2 (VSS), D29.2 (VSS), D30.2 (VSS), D31.2 (VSS), D32.2 (VSS), D33.2 (VSS), GND1.1, J1.6 (GND), J1.9 (GND), J1.14 (GND), J1.20 (GND), J1.25 (GND), J1.30 (GND), J1.34 (GND), J1.39 (GND), J3.6, R9.1, R10.1, R11.1, SW25.C, SW29.C, U27.3 (GND); also elsewhere on the board
unnamed: C1.1, R1.2, R3.1, SW25.A
unnamed: C2.1, R2.2, R4.1, SW25.B
unnamed: C3.1, R5.1, R7.2, SW29.B
unnamed: C4.1, R6.1, R8.2, SW29.A
unnamed: D1.3 (DIN), D25.1 (DOUT)
unnamed: D1.1 (DOUT), D2.3 (DIN)
unnamed: D2.1 (DOUT), D3.3 (DIN)
unnamed: D3.1 (DOUT), D4.3 (DIN)
unnamed: D4.1 (DOUT), D5.3 (DIN)
unnamed: D5.1 (DOUT), D6.3 (DIN)
unnamed: D6.1 (DOUT), D7.3 (DIN)
unnamed: D7.1 (DOUT), D8.3 (DIN)
unnamed: D8.1 (DOUT), D9.3 (DIN)
unnamed: D9.1 (DOUT), D10.3 (DIN)
unnamed: D10.1 (DOUT), D11.3 (DIN)
unnamed: D11.1 (DOUT), D12.3 (DIN)
unnamed: D12.1 (DOUT), D13.3 (DIN)
unnamed: D13.1 (DOUT), D14.3 (DIN)
unnamed: D14.1 (DOUT), D15.3 (DIN)
unnamed: D15.1 (DOUT), D16.3 (DIN)
unnamed: D16.1 (DOUT), D27.3 (DIN)
unnamed: D17.3 (DIN), D27.1 (DOUT)
unnamed: D17.1 (DOUT), D18.3 (DIN)
unnamed: D18.1 (DOUT), D19.3 (DIN)
unnamed: D19.1 (DOUT), D20.3 (DIN)
unnamed: D20.1 (DOUT), D21.3 (DIN)
unnamed: D21.1 (DOUT), D22.3 (DIN)
unnamed: D22.1 (DOUT), D23.3 (DIN)
unnamed: D23.1 (DOUT), D24.3 (DIN)
unnamed: D24.1 (DOUT), D28.3 (DIN)
unnamed: D25.3 (DIN), D26.1 (DOUT)
unnamed: D26.3 (DIN), R23.1
unnamed: D28.1 (DOUT), D29.3 (DIN)
unnamed: D29.1 (DOUT), D30.3 (DIN)
unnamed: D30.1 (DOUT), D31.3 (DIN)
unnamed: D31.1 (DOUT), D32.3 (DIN)
unnamed: D32.1 (DOUT), D33.3 (DIN)
unnamed: SW1.1 (A), U25.2 (A)
unnamed: SW2.1 (A), U1.2 (A)
unnamed: SW3.1 (A), U2.2 (A)
unnamed: SW4.1 (A), U3.2 (A)
unnamed: SW5.1 (A), U4.2 (A)
unnamed: SW6.1 (A), U5.2 (A)
unnamed: SW7.1 (A), U6.2 (A)
unnamed: SW8.1 (A), U7.2 (A)
unnamed: SW9.1 (A), U8.2 (A)
unnamed: SW10.1 (A), U9.2 (A)
unnamed: SW11.1 (A), U10.2 (A)
unnamed: SW12.1 (A), U11.2 (A)
unnamed: SW13.1 (A), U12.2 (A)
unnamed: SW14.1 (A), U13.2 (A)
unnamed: SW15.1 (A), U14.2 (A)
unnamed: SW16.1 (A), U15.2 (A)
unnamed: SW17.1 (A), U16.2 (A)
unnamed: SW18.1 (A), U17.2 (A)
unnamed: SW19.1 (A), U18.2 (A)
unnamed: SW20.1 (A), U19.2 (A)
unnamed: SW21.1 (A), U20.2 (A)
unnamed: SW22.1 (A), U21.2 (A)
unnamed: SW23.1 (A), U22.2 (A)
unnamed: SW24.1 (A), U23.2 (A)
unnamed: SW26.1 (A), U24.2 (A)
unnamed: SW27.1 (A), U26.2 (A)
unnamed: SW28.1 (A), U28.2 (A)
unnamed: R23.2, U27.4 (Y)

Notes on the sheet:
6 NeoPixels Bank-Selection
8 NeoPixels @Edit-Keys
Note: the display is directly connected to the Raspberry Pi. The 3.3V is routet directly from the RPi to the Display (and only to the display)
2 NeoPixels @Left/Right-Keys
"NeoPixels" keyboard illumination
Raspberry Pi 5 GPIOs (40-Pin Header)
Keyboard Matrix
SPI-Display (routet from Raspberry Pi GPIO to OLED)
16 NeoPixels @Media-Slot-Keys
NeoPixel @Fn-Key
PiPico 2040

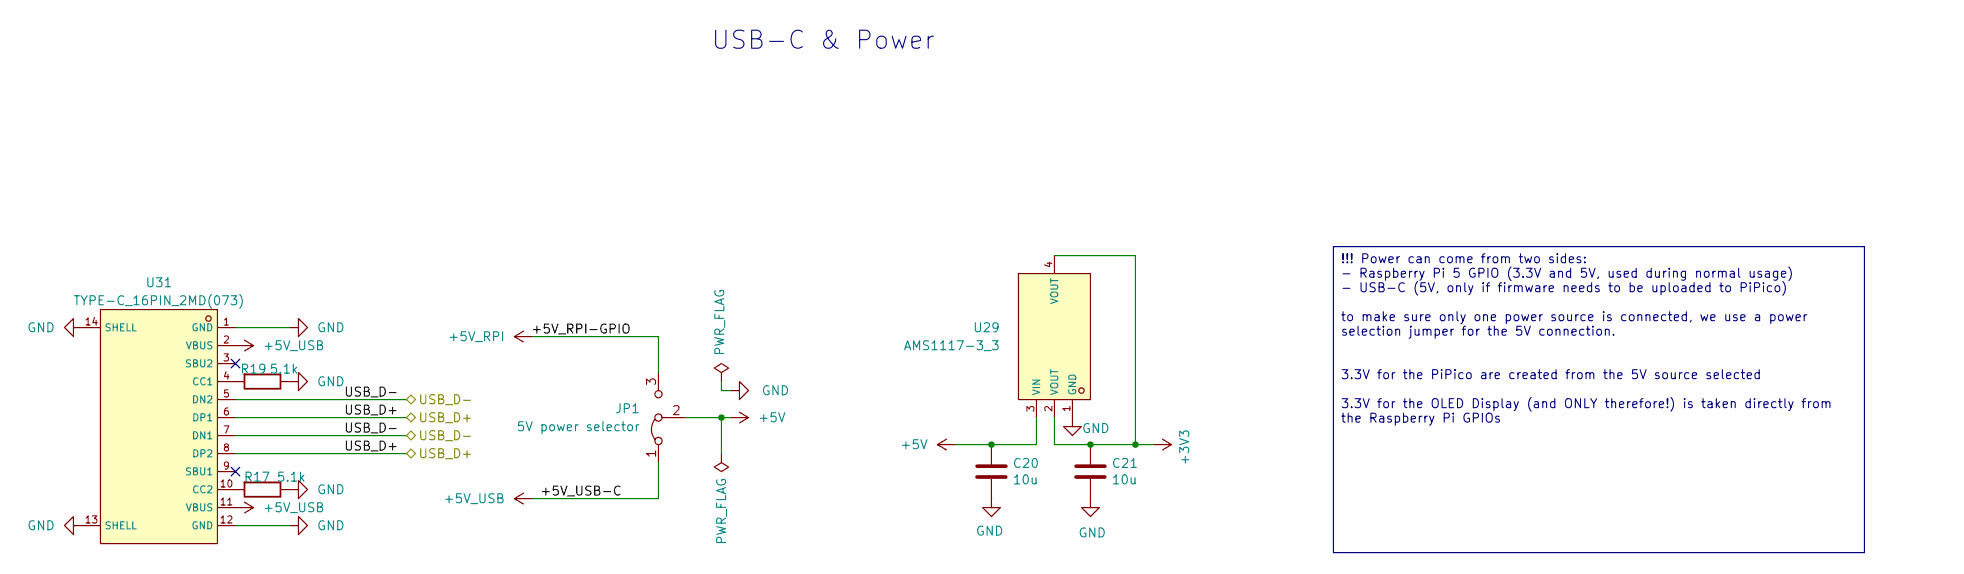
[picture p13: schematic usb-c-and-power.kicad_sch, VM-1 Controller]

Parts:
C20, C21: 10u; CP_EIA-3216-10_Kemet-I; LCSC C7171
JP1: 5V power selector; PinHeader_1x03_P2.54mm_Vertical
R17, R19: 5.1k; R_0402_1005Metric
U29: AMS1117-3_3; SOT-223-3_L6.5-W3.4-P2.30-LS7.0-BR; LCSC C6186
U31: TYPE-C_16PIN_2MD(073); USB-C-SMD_TYPE-C-6PIN-2MD-073; LCSC C2765186

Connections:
+3V3: C21.1, U29.2 (VOUT), U29.4 (VOUT); also elsewhere on the board
+5V: C20.1, JP1.2 (C), U29.3 (VIN); also elsewhere on the board
+5V_RPI: JP1.3 (B); also elsewhere on the board
+5V_USB: JP1.1 (A), U31.2 (VBUS), U31.11 (VBUS)
/Pi Pico 2040/USB_D+: U31.6 (DP1), U31.8 (DP2); also elsewhere on the board
/Pi Pico 2040/USB_D-: U31.5 (DN2), U31.7 (DN1); also elsewhere on the board
GND: C20.2, C21.2, R17.1, R19.1, U29.1 (GND), U31.1 (GND), U31.12 (GND), U31.13 (SHELL), U31.14 (SHELL); also elsewhere on the board
unnamed: R19.2, U31.4 (CC1)
unnamed: R17.2, U31.10 (CC2)

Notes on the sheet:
USB-C & Power
!!! Power can come from two sides: - Raspberry Pi 5 GPIO (3.3V and 5V, used during normal usage) - USB-C (5V, only if firmware needs to be uploaded to PiPico) to make sure only one power source is connected, we use a power selection jumper for the 5V connection. 3.3V for the PiPico are created from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

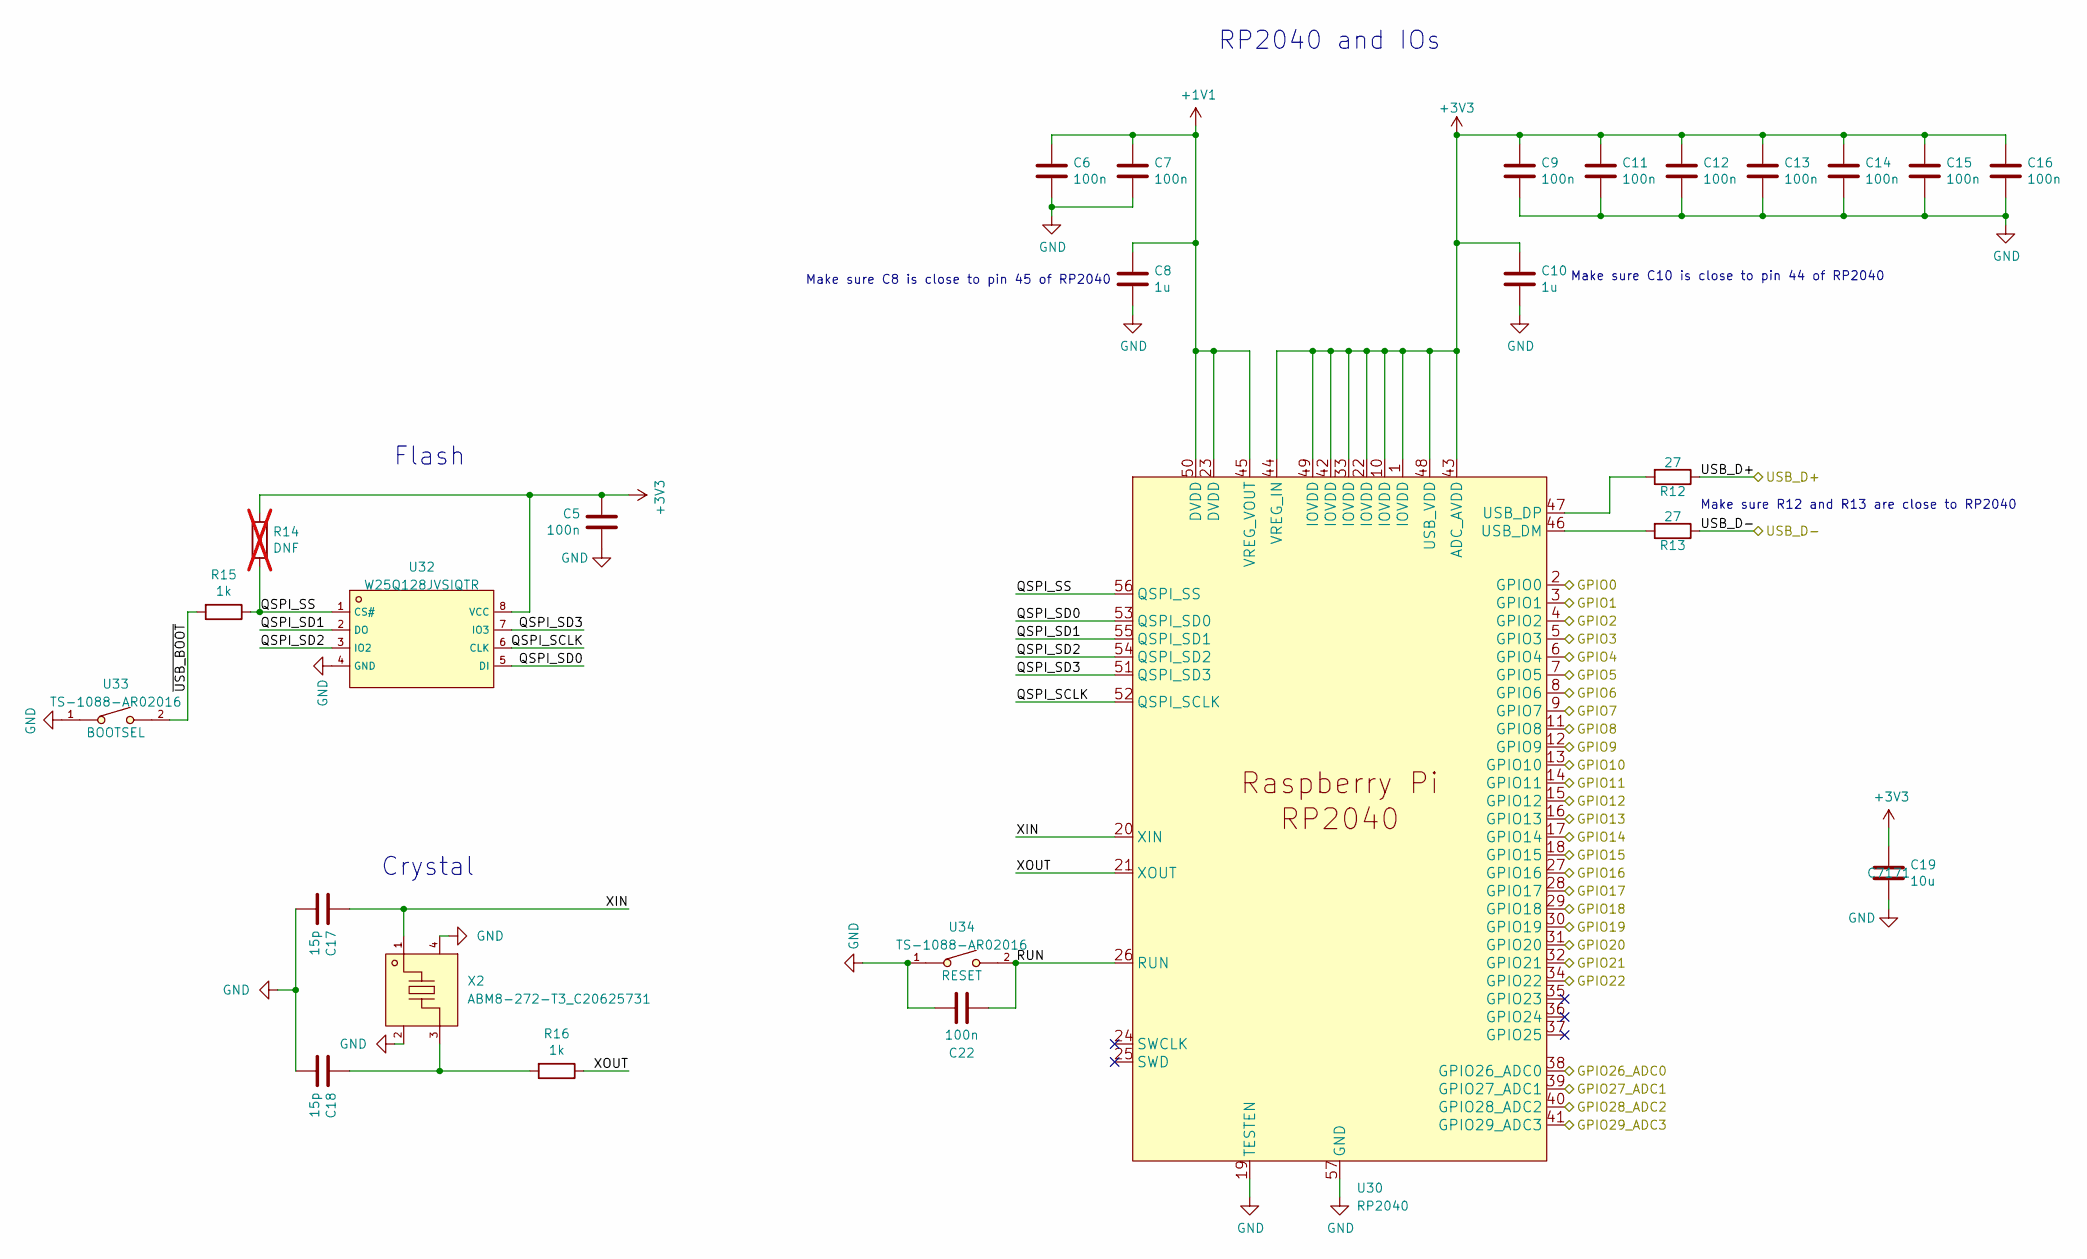
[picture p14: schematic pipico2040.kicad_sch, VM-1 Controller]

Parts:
C5, C6, C7, C9, C11, C12, C13, C14, C15, C16, C22: 100n; C_0402_1005Metric
C8, C10: 1u; C_0402_1005Metric; LCSC C52923
C17, C18: 15p; C_0402_1005Metric
C19: 10u; CP_EIA-3216-10_Kemet-I; LCSC C7171
R12, R13: 27; R_0402_1005Metric
R14: DNF; R_0402_1005Metric; not fitted
R15, R16: 1k; R_0402_1005Metric
U30: RP2040; RP2040-QFN-56; LCSC C2040
U32: W25Q128JVSIQTR; SOIC-8_L5.3-W5.3-P1.27-LS8.0-BL; LCSC C97521
U33, U34: TS-1088-AR02016; SW-SMD_L3.9-W3.0-P4.45; LCSC C720477
X2: ABM8-272-T3_C20625731; CRYSTAL-SMD_4P-L3.2-W2.5-BL; LCSC C20625731

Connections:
+1V1: C6.1, C7.1, C8.1, U30.23 (DVDD), U30.45 (VREG_VOUT), U30.50 (DVDD)
+3V3: C5.1, C9.1, C10.1, C11.1, C12.1, C13.1, C14.1, C15.1, C16.1, C19.1, R14.1, U30.1 (IOVDD), U30.10 (IOVDD), U30.22 (IOVDD), U30.33 (IOVDD), U30.42 (IOVDD), U30.43 (ADC_AVDD), U30.44 (VREG_IN), U30.48 (USB_VDD), U30.49 (IOVDD), U32.8 (VCC); also elsewhere on the board
/COL1: U30.9 (GPIO7); also elsewhere on the board
/COL2: U30.11 (GPIO8); also elsewhere on the board
/COL3: U30.12 (GPIO9); also elsewhere on the board
/COL4: U30.13 (GPIO10); also elsewhere on the board
/COL5: U30.14 (GPIO11); also elsewhere on the board
/COL6: U30.15 (GPIO12); also elsewhere on the board
/COL7: U30.16 (GPIO13); also elsewhere on the board
/COL8: U30.17 (GPIO14); also elsewhere on the board
/COL9: U30.18 (GPIO15); also elsewhere on the board
/I2C_SCL: U30.32 (GPIO21); also elsewhere on the board
/I2C_SDA: U30.31 (GPIO20); also elsewhere on the board
/Pi Pico 2040/GPIO0: U30.2 (GPIO0)
/Pi Pico 2040/GPIO1: U30.3 (GPIO1)
/Pi Pico 2040/GPIO2: U30.4 (GPIO2)
/Pi Pico 2040/GPIO3: U30.5 (GPIO3)
/Pi Pico 2040/GPIO26_ADC0: U30.38 (GPIO26_ADC0); also elsewhere on the board
/Pi Pico 2040/GPIO27_ADC1: U30.39 (GPIO27_ADC1); also elsewhere on the board
/Pi Pico 2040/GPIO28_ADC2: U30.40 (GPIO28_ADC2); also elsewhere on the board
/Pi Pico 2040/GPIO29_ADC3: U30.41 (GPIO29_ADC3); also elsewhere on the board
/Pi Pico 2040/QSPI_SCLK: U30.52 (QSPI_SCLK), U32.6 (CLK)
/Pi Pico 2040/QSPI_SD0: U30.53 (QSPI_SD0), U32.5 (DI)
/Pi Pico 2040/QSPI_SD1: U30.55 (QSPI_SD1), U32.2 (DO)
/Pi Pico 2040/QSPI_SD2: U30.54 (QSPI_SD2), U32.3 (IO2)
/Pi Pico 2040/QSPI_SD3: U30.51 (QSPI_SD3), U32.7 (IO3)
/Pi Pico 2040/QSPI_SS: R14.2, R15.1, U30.56 (QSPI_SS), U32.1 (CS#)
/Pi Pico 2040/RUN: C22.2, U30.26 (RUN), U34.2
/Pi Pico 2040/USB_D+: R12.1; also elsewhere on the board
/Pi Pico 2040/USB_D-: R13.1; also elsewhere on the board
/Pi Pico 2040/XIN: C17.1, U30.20 (XIN), X2.1
/Pi Pico 2040/XOUT: R16.1, U30.21 (XOUT)
/Pi Pico 2040/~USB_BOOT: R15.2, U33.2
/ROTARY_1_A: U30.28 (GPIO17); also elsewhere on the board
/ROTARY_1_B: U30.27 (GPIO16); also elsewhere on the board
/ROTARY_2_A: U30.30 (GPIO19); also elsewhere on the board
/ROTARY_2_B: U30.29 (GPIO18); also elsewhere on the board
/ROW1: U30.8 (GPIO6); also elsewhere on the board
/ROW2: U30.7 (GPIO5); also elsewhere on the board
/ROW3: U30.6 (GPIO4); also elsewhere on the board
/WS2812B: U30.34 (GPIO22); also elsewhere on the board
GND: C5.2, C6.2, C7.2, C8.2, C9.2, C10.2, C11.2, C12.2, C13.2, C14.2, C15.2, C16.2, C17.2, C18.2, C19.2, C22.1, U30.19 (TESTEN), U30.57 (GND), U32.4 (GND), U33.1, U34.1, X2.2 (GND), X2.4 (GND); also elsewhere on the board
unnamed: C18.1, R16.2, X2.3
unnamed: R13.2, U30.46 (USB_DM)
unnamed: R12.2, U30.47 (USB_DP)

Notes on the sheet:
Make sure R12 and R13 are close to RP2040
Crystal
Flash
RP2040 and IOs
Make sure C10 is close to pin 44 of RP2040
Make sure C8 is close to pin 45 of RP2040

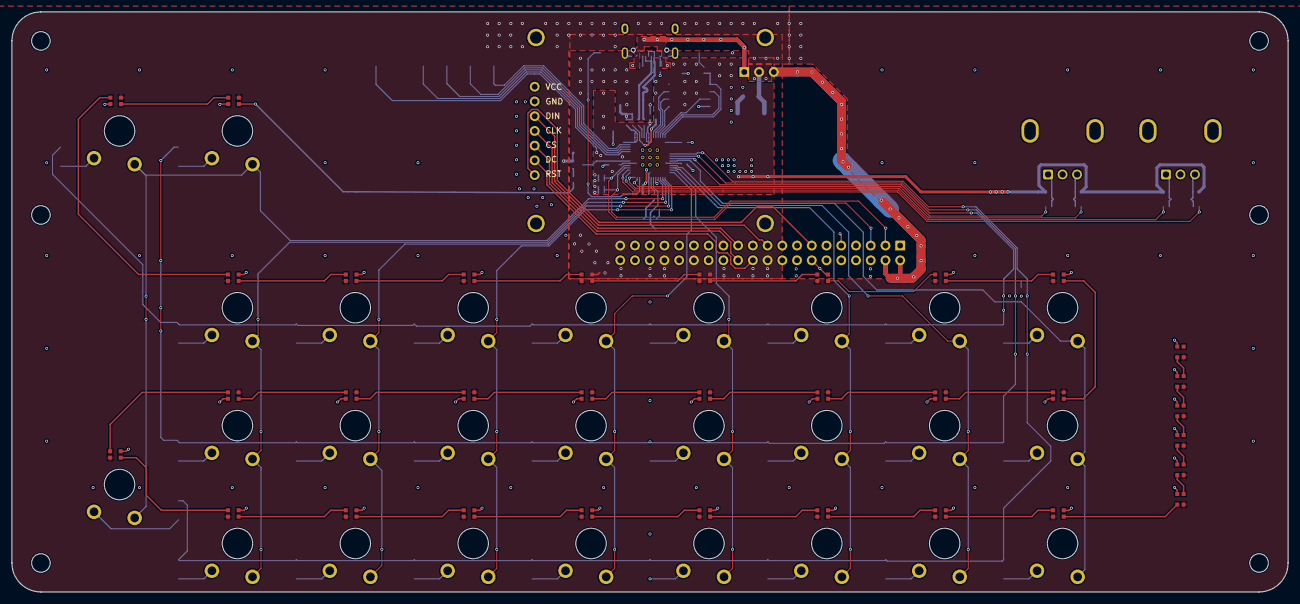
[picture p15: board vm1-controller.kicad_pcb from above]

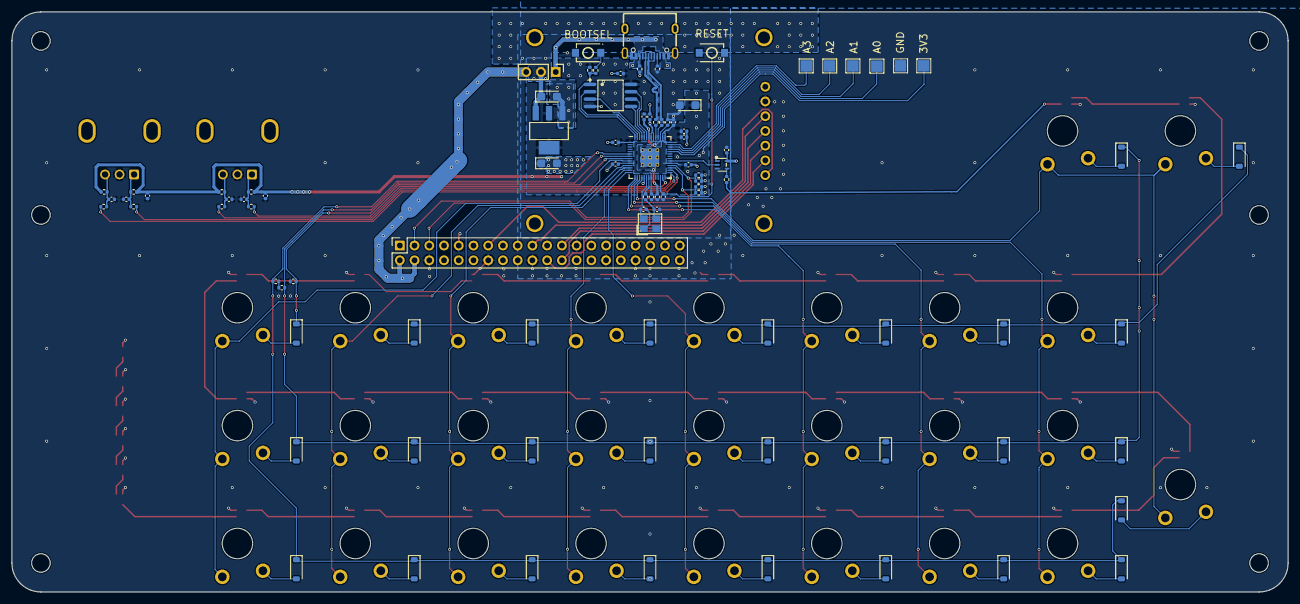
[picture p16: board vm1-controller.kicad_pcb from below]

Board: 4 copper layers, 220.0 x 100.0 mm, 160 parts (91 on the bottom side), 117 nets.

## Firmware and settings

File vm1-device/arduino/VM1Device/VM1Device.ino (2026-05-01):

#include <stdint.h>
#include <stdio.h>
#include <Wire.h>

#include "pico/stdlib.h"
#include "hardware/gpio.h"

#include "src/RotaryEncoder.h"
#include "src/ButtonMatrix.h"
#include "src/DeviceBufferController.h"
#include "src/StateController.h"
#include "src/ButtonLEDs.h"
#include "src/AverageFilter.h"

#define I2C_SLAVE_ADDRESS 0x08

volatile uint8_t i2cBuffer[sizeof(DeviceState)];
volatile uint8_t i2cIndex = 0;
volatile bool i2cFrameReady = false;

unsigned long current_millis;
unsigned long millis_old = 0;


// analog inputs
const uint8_t analogInputPins[] = {26, 27, 28, 29};
AverageFilter analogInputFilters[ANALOG_INPUTS_COUNT];

DeviceBuffer deviceBuffer = {};   // output buffer for events. Gets cleared after events are sent via i2c
DeviceState deviceState = {};     // state for the neopixel display, rotary encoder sensitivity etc.
int8_t lastPressedMediaButtonId = -1;

void showDebugMessage()
{
  unsigned long current_millis = millis();
  static long time = 0;
  if (current_millis - time > 1000)
  {
    time = current_millis;
    Serial.printf("EventType: %d, ButtonId: %d\r\n", deviceBuffer.buttonEvents[0].eventType, deviceBuffer.buttonEvents[0].buttonId);
    Serial.printf("device buffer size: %d\r\n", sizeof(deviceBuffer));
    Serial.printf("buttonEvent size: %d\r\n", sizeof(ButtonEvent));
    Serial.printf("ShiftKey: %d\r\n", deviceBuffer.fnPressed );
  }
}

void onI2CRequestHandler()
{
  Wire.write(reinterpret_cast<const uint8_t *>(&deviceBuffer), sizeof(deviceBuffer));
  clearEventBuffer();
}

void onI2CReceiveHandler(int numBytes)
{
    while (Wire.available())
    {
        if (i2cIndex < sizeof(DeviceState))
        {
            i2cBuffer[i2cIndex++] = Wire.read();
        }
        else
        {
            Wire.read(); // discard overflow
        }
    }

    // frame complete?
    if (i2cIndex >= sizeof(DeviceState))
    {
        i2cFrameReady = true;
    }
}

void setup()
{
  Serial.begin(115200);

  initButtonMatrix();
  initRotaryEncoders();
  initNeoPixels();
  clearEventBuffer();

  Wire.setSDA(20); // GP20 = SDA
  Wire.setSCL(21); // GP21 = SCL
  Wire.begin(I2C_SLAVE_ADDRESS);
  Wire.onRequest(onI2CRequestHandler);
  Wire.onReceive(onI2CReceiveHandler);

  startupAnimation();
}

void loop()
{
  current_millis = millis();
  
  updateButtonMatrix();
  updateRotaryEncoders();

  if (i2cFrameReady)
  {
      noInterrupts();  // protect shared buffer flag

      memcpy(&deviceState,
              (void*)i2cBuffer,
              sizeof(DeviceState));

      i2cIndex = 0;
      i2cFrameReady = false;

      interrupts();

      // DEBUG OUTPUT
      Serial.println("Received DeviceState:");

      for (int i = 0; i < 16; i++)
      {
          Serial.printf("[%d] ", i);

          uint8_t s = deviceState.mediaButtonsStates[i];

          if (s & ASSIGNED_MASK) Serial.print("ASSIGNED ");
          if (s & PLAYING_MASK)  Serial.print("PLAYING ");
          if (s & FOCUSED_MASK)  Serial.print("FOCUSED ");

          if (s == 0) Serial.print("EMPTY");

          Serial.println();
      }
  }

 
  if (current_millis - millis_old > 16)
  {
    millis_old = current_millis;
    updateNeoPixels();
  }

  for(int i = 0; i < ANALOG_INPUTS_COUNT; ++i)
  {
    float analogIn = analogRead(analogInputPins[i]);
    deviceBuffer.analogInput[i] = analogInputFilters[i].Filter(analogIn);    
  }
  
  // showDebugMessage();
}

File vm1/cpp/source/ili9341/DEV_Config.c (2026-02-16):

/*****************************************************************************
 * | File      	:   DEV_Config.c
 * | Author      :   Hardware interface for ILI9341
 * | Function    :   Hardware underlying interface
 ******************************************************************************/
#include "DEV_Config.h"
#include <unistd.h>

#if USE_DEV_LIB

static int ILI9341_GPIO_Handle = -1;
int ILI9341_SPI_Handle = -1;  // Non-static so ILI9341.c can access it

#endif

/*****************************************
                GPIO
*****************************************/
void ILI9341_DEV_Digital_Write(UWORD Pin, UBYTE Value)
{
#ifdef USE_BCM2835_LIB
    bcm2835_gpio_write(Pin, Value);

#elif USE_WIRINGPI_LIB
    digitalWrite(Pin, Value);

#elif USE_DEV_LIB
    lgGpioWrite(ILI9341_GPIO_Handle, Pin, Value);

#endif
}

UBYTE ILI9341_DEV_Digital_Read(UWORD Pin)
{
    UBYTE Read_value = 0;
#ifdef USE_BCM2835_LIB
    Read_value = bcm2835_gpio_lev(Pin);

#elif USE_WIRINGPI_LIB
    Read_value = digitalRead(Pin);

#elif USE_DEV_LIB
    Read_value = lgGpioRead(ILI9341_GPIO_Handle, Pin);
#endif
    return Read_value;
}

void ILI9341_DEV_GPIO_Mode(UWORD Pin, UWORD Mode)
{
#ifdef USE_BCM2835_LIB
    if (Mode == 0 || Mode == BCM2835_GPIO_FSEL_INPT)
    {
        bcm2835_gpio_fsel(Pin, BCM2835_GPIO_FSEL_INPT);
    }
    else
    {
        bcm2835_gpio_fsel(Pin, BCM2835_GPIO_FSEL_OUTP);
    }
#elif USE_WIRINGPI_LIB
    if (Mode == 0 || Mode == INPUT)
    {
        pinMode(Pin, INPUT);
        pullUpDnControl(Pin, PUD_UP);
    }
    else
    {
        pinMode(Pin, OUTPUT);
    }
#elif USE_DEV_LIB
    if (Mode == 0 || Mode == LG_SET_INPUT)
    {
        lgGpioClaimInput(ILI9341_GPIO_Handle, LFLAGS, Pin);
    }
    else
    {
        lgGpioClaimOutput(ILI9341_GPIO_Handle, LFLAGS, Pin, LG_LOW);
    }
#endif
}

/**
 * delay x ms
 **/
void ILI9341_DEV_Delay_ms(UDOUBLE xms)
{
#ifdef USE_BCM2835_LIB
    bcm2835_delay(xms);
#elif USE_WIRINGPI_LIB
    delay(xms);
#elif USE_DEV_LIB
    lguSleep(xms / 1000.0);
#endif
}

static void ILI9341_DEV_GPIO_Init(void)
{
    ILI9341_DEV_GPIO_Mode(ILI9341_CS, 1);
    ILI9341_DEV_GPIO_Mode(ILI9341_RST, 1);
    ILI9341_DEV_GPIO_Mode(ILI9341_RS, 1);
    // ILI9341_DEV_GPIO_Mode(ILI9341_LED, 1);
    
    // Set initial states
    ILI9341_CS_1;  // CS high (inactive)
    ILI9341_RST_1; // Reset high
    ILI9341_RS_0;  // Command mode
    // ILI9341_LED_1; // Backlight on
}

/******************************************************************************
function:	Module Initialize, the library and initialize the pins, SPI protocol
parameter:
Info:
******************************************************************************/
UBYTE ILI9341_DEV_ModuleInit(void)
{
#ifdef USE_BCM2835_LIB
    if (!bcm2835_init())
    {
        printf("ILI9341: bcm2835 init failed !!! \r\n");
        return 1;
    }
    else
    {
        printf("ILI9341: bcm2835 init success !!! \r\n");
    }
    ILI9341_DEV_GPIO_Init();
#if USE_SPI
    printf("ILI9341: USE_SPI\r\n");
    bcm2835_spi_begin();
    bcm2835_spi_setBitOrder(BCM2835_SPI_BIT_ORDER_MSBFIRST);
    bcm2835_spi_setDataMode(BCM2835_SPI_MODE0);
    bcm2835_spi_setClockDivider(BCM2835_SPI_CLOCK_DIVIDER_4);
    bcm2835_spi_chipSelect(BCM2835_SPI_CS0);
    bcm2835_spi_setChipSelectPolarity(BCM2835_SPI_CS0, LOW);
#endif

#elif USE_WIRINGPI_LIB
    if (wiringPiSetupGpio() < 0)
    {
        printf("ILI9341: set wiringPi lib failed !!! \r\n");
        return 1;
    }
    else
    {
        printf("ILI9341: set wiringPi lib success !!! \r\n");
    }
    ILI9341_DEV_GPIO_Init();
#if USE_SPI
    printf("ILI9341: USE_SPI\r\n");
    wiringPiSPISetupMode(0, 32000000, 0);
#endif

#elif USE_DEV_LIB
    ILI9341_GPIO_Handle = lgGpiochipOpen(0);
    if (ILI9341_GPIO_Handle < 0)
    {
        printf("ILI9341: gpiochip0 Export Failed\n");
        return -1;
    }

    ILI9341_DEV_GPIO_Init();

#if USE_SPI
    printf("ILI9341: USE_SPI\r\n");
    printf("ILI9341: Attempting to open SPI bus 0, device 0...\n");
    ILI9341_SPI_Handle = lgSpiOpen(0, 0, 40000000, 0);  // 40MHz for faster refresh
    if (ILI9341_SPI_Handle < 0)
    {
        printf("ILI9341: SPI open failed with error %d\n", ILI9341_SPI_Handle);
        printf("ILI9341: Trying SPI bus 0, device 1 instead...\n");
        ILI9341_SPI_Handle = lgSpiOpen(0, 1, 40000000, 0);  // 40MHz
        if (ILI9341_SPI_Handle < 0)
        {
            printf("ILI9341: SPI device 1 also failed with error %d\n", ILI9341_SPI_Handle);
            return -1;
        }
        printf("ILI9341: SPI device 1 opened successfully, handle=%d\n", ILI9341_SPI_Handle);
    } else {
        printf("ILI9341: SPI opened successfully, handle=%d\n", ILI9341_SPI_Handle);
    }
#endif
#endif
    return 0;
}

int ILI9341_DEV_SPI_WriteByte(uint8_t Value)
{
#ifdef USE_BCM2835_LIB
    bcm2835_spi_transfer(Value);
    return 0;

#elif USE_WIRINGPI_LIB
    wiringPiSPIDataRW(0, &Value, 1);
    return 0;
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

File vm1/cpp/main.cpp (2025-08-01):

/*
 * Copyright (c) 2023-2025 Nils Zweiling & Julian Jungel
 *
 * This file is part of VM-1 which is released under the MIT license.
 * See file LICENSE or go to https://github.com/zwodev/vm1-video-mixer/tree/master/LICENSE
 * for full license details.
 *
 * Parts of this file have been taken from:
 * https://github.com/libsdl-org/SDL/blob/main/test/testffmpeg.c
 *
 */

#include "VM1Application.h"

int main(int, char **)
{
    VM1Application vm1;
    if (!vm1.exec()) return 1;
    // while (true) {
    //     if(!vm1.exec()) break;
    // };

    return 0;
}

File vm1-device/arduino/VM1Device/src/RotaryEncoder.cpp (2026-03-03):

#include <Arduino.h>
#include "hardware/gpio.h"
#include "pico/time.h"

#include "RotaryEncoder.h"
#include "DeviceBufferController.h"
#include "StateController.h"

#define DEBOUNCE_US 1000  // 1 ms debounce

static rotary_encoder_t* enc_a[32] = { 0 };

rotary_encoder_t encoder0;
rotary_encoder_t encoder1;
int32_t encoder0_position;
int32_t encoder1_position;

int encoder0_press_up = 0;
int encoder0_press_down = 0;
int encoder1_press_up = 0;
int encoder1_press_down = 0;


const int8_t transition_table[4][4] = {
  { 0, +1, -1, 0 },
  { -1, 0, 0, +1 },
  { +1, 0, 0, -1 },
  { 0, -1, +1, 0 },
};

void initRotaryEncoders(){
  encoder0 = {.pin_a = ROTARY_0_PIN_A, .pin_b = ROTARY_0_PIN_B};
  encoder1 = {.pin_a = ROTARY_1_PIN_A, .pin_b = ROTARY_1_PIN_B};
  rotary_encoder_init(&encoder0);
  rotary_encoder_init(&encoder1);

}

void updateRotaryEncoders() {
  int8_t enc0 = 0;
  if (enc0 = rotary_encoder_process(&encoder0, encoder0_position))
  {
    if (enc0 < 0)
    {
      encoder0_press_down = 0;
      encoder0_press_up++;
      if(encoder0_press_up % deviceState.rotarySensitivity == 0) { 
        addButtonEventToBuffer({EventType::ROTARY_EVENT, 0});
      }
    }
    else if (enc0 > 0)
    {
      encoder0_press_up = 0;
      encoder0_press_down++;
      if(encoder0_press_down % deviceState.rotarySensitivity == 0) {
        addButtonEventToBuffer({EventType::ROTARY_EVENT, 1});
      }
    }
  }
  
  int8_t enc1 = 0;
  if (enc1 = rotary_encoder_process(&encoder1, encoder1_position))
  {    
    if (enc1 < 0)
    {
      encoder1_press_down = 0;
      encoder1_press_up++;
      if(encoder1_press_up % deviceState.rotarySensitivity == 0) { 
        addButtonEventToBuffer({EventType::ROTARY_EVENT, 2});
      }
    }
    else if (enc1 > 0)
    {
      encoder1_press_up = 0;
      encoder1_press_down++;
      if(encoder1_press_down % deviceState.rotarySensitivity == 0) {
        addButtonEventToBuffer({EventType::ROTARY_EVENT, 3});
      }
    }
  }

}

void rotary_encoder_init(rotary_encoder_t* enc) {
  gpio_init(enc->pin_a);
  gpio_set_dir(enc->pin_a, GPIO_IN);
  gpio_pull_up(enc->pin_a);

  gpio_init(enc->pin_b);
  gpio_set_dir(enc->pin_b, GPIO_IN);
  gpio_pull_up(enc->pin_b);

  enc->position = 0;
  enc->last_change_us = time_us_32();

  enc_a[enc->pin_a] = enc;  // register this encoder by pin A
  enc_a[enc->pin_b] = enc;  // register this encoder by pin B

  enc->last_stable_state = (gpio_get(enc->pin_a) << 1) | gpio_get(enc->pin_b);

  gpio_set_irq_enabled_with_callback(
    enc->pin_a,
    GPIO_IRQ_EDGE_FALL | GPIO_IRQ_EDGE_RISE,
    true,
    &gpio_callback);

  gpio_set_irq_enabled(
    enc->pin_b,
    GPIO_IRQ_EDGE_FALL | GPIO_IRQ_EDGE_RISE,
    true);
}

int8_t rotary_encoder_process(rotary_encoder_t* enc, int32_t& position) {
  int8_t change = 0;
  if (!enc->state_changed_flag) return change;

  uint32_t now = time_us_32();
  if ((now - enc->last_change_us) >= DEBOUNCE_US) {
    // stable for at least debounce time
    if (enc->last_read_state != enc->last_stable_state) {
      int8_t movement = transition_table[enc->last_stable_state][enc->last_read_state];
      if (movement != 0) {
        enc->position += movement;
        position = enc->position;
        change = movement;
      }
      enc->last_stable_state = enc->last_read_state;
    }
    enc->state_changed_flag = false;
  }
  return change;
}

void gpio_callback(uint gpio, uint32_t events) {
  // get the correct rotary encoder from the static list:
  rotary_encoder_t* enc = enc_a[gpio];
  if (!enc) return;

  uint8_t a = gpio_get(enc->pin_a);
  uint8_t b = gpio_get(enc->pin_b);

  uint8_t current_state = (a << 1) | b;

  if (current_state != enc->last_read_state) {
    enc->last_read_state = current_state;
    enc->last_change_us = time_us_32();
    enc->state_changed_flag = true;
  }
}

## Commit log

2023-10-17 Video switching (WIP).
2023-10-19 Cycling through videos and camera.
2024-04-01 Fixed links in header comments and README.
    [main.cpp]
2025-02-05 Works with current versions of SDL (3.2.2) and Dear Imgui.
2025-02-05 Implemented threaded video decoding (WIP).
2025-02-20 Added CameraRenderer (hdmi2csi).
2025-02-26 initial commit clockdiv
    - first prototype of the vm-1 pcb (hardware, firmware)
    - 3d file for prototype baseplate
    [20231027_vm-1_prototyp-CuBottom.gbr, 20231027_vm-1_prototyp-CuTop.gbr, 20231027_vm-1_prototyp-EdgeCuts.gbr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]
2025-02-28 Added CameraController (WIP).
2025-03-18 hid-keyboard; button matrix
    implementation of a new PiPico-Library (by Earle Philhower) to use a hid-keyboard that support key-press/release;
    also made an own button-matrix to support key-press/release
2025-03-19 vm-1 keyboard prototype
    added keyboard-press and -release
2025-03-20 button registry
2025-04-02 UI, Menu and Buttons
2025-04-03 Added threading to OLED routines.
2025-04-15 Added filter for hdmi dummy file for testing.
2025-04-18 Extracted getBuffer from lockBuffer in CameraPlayer.
2025-04-18 Added lockBuffer/unlockBuffer for CameraPlayer in main.
2025-04-22 Fixed issues UI related issues.
    [main.cpp]
2025-04-29 Fixed HDMI playing issue and setup EDID on start.
    [Registry.h, main.cpp]
2025-05-01 autostart of vm1 and localsend
    [config.txt]
2025-05-13 added NeoPixels to VM1-Controller; todo: fix rotary encoder
    [main.cpp]
2025-05-14 new encoder library
2025-05-15 Sending controller state is implemented. TODO: Open serial device.
2025-05-15 UI improvements, bug-fixing and hashing registry snapshots.
    [Registry.h, main.cpp]
2025-05-16 new rotary encoder implementation
2025-05-16 Removed file filters.
2025-05-17 Bank switching works (with led indicators), auto-save works.
2025-05-17 Added Network info screen (edit button 7).
2025-05-31 Quick fix for letterboxed mode.
    [main.cpp]
2025-06-12 i2c test
2025-06-12 added i2c to VM1-controller
2025-06-12 rotary encoder library
2025-06-12 rotary encoder
2025-06-13 VM-1 Controller V2.0
    ordered at jlcpcb
    [1_5inch-rgb-oled-module_asm-1110.stp, 7377754.stp, bom.csv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]
2025-06-30 Adding abstract class MediaPlayer (used for CameraPlayer/VideoPlayer).
2025-07-02 Camera and video playback work in compute-shader test.
2025-07-02 Showing active media slots seems to work.
2025-07-08 update VM-1 controller to PCB v2
2025-07-08 added arduino library descriptions
2025-07-14 SPI now on gpiochip 0.
2025-07-17 Added deploy folder for rpi-image-gen.
    [config.txt, vm1-basic.cfg]
2025-07-18 board connector
    connects io-board with vm1-device
    [vm1-board-connector.kicad_pcb, vm1-board-connector.kicad_sch]
2025-07-24 VM1-Device update to pcb v2
2025-07-24 added i2c to KeyboardController WIP
2025-07-25 removed obsolete files from vm1-controller
    [raspberrypi-swd.cfg]
2025-07-25 sends keyboard buffer to i2c
2025-07-25 vm1-device minor cleanup
2025-07-25 DeviceController via i2c working
2025-07-25 i2c connection to vm1-device works
2025-07-30 DeviceController lights up selected EditButton
2025-07-30 prevent video playback when fn key is pressed
    [DeviceController.cpp]
2025-07-30 fixed FadeTime value change with Encoder
    [DeviceController.cpp]
2025-07-30 show selected (but not triggered) media button in different state/color
2025-07-30 added MEDIABUTTON_SELECTED to ButtonState
2025-08-01 Smooth audio transitions (per plane) and memory leak hunting.
    [DEV_Config.c, DeviceController.cpp]
2025-08-13 Fixed: Popping fade when volume is smaller than 10.
    [Registry.h]
2025-08-13 Added filter so HDR videos are not played (BT.2020).
2025-08-14 Fixed HDMI/camera shader.
2025-08-14 VM-1 Device rotary sensitivity
2025-08-14 debugging: cameraplayer, videoplayer
2025-08-14 rpi image deploy
    [config.txt]
2025-08-14 Added queuing (for thread safety) to EventBus.
2025-08-18 Added reset functionality and fixed aspect ratio/resolution issues.
    [Registry.h]
2025-08-19 HDMI input reset works now when scanning for new devices.
2025-08-20 Reworked keyboard input and remapped edit/media keys.
    [Registry.h]
2025-08-21 Added clear slot and re-arranged menus.
2025-08-21 Showing button matrix on edit button 6 now.
2025-11-19 UVC capture works. Added switching CSI/UVC.
2025-12-19 prototype to fade video with manual poti
2025-12-22 wip prototype; use external fader
2026-02-23 visual/color indication for "Shader" in ButtonMatrix and for the DeviceController
2026-02-23 Mapping Mode prototype
2026-02-23 Mapping Mode prototype, Arduino/DeviceController
2026-02-26 Screen Rotation Prototype
2026-02-26 Mapping Mode with SpinBoxVec2; added second rotary encoder functionality
2026-02-27 Reverted special mapping mode. Mapping is done through spin boxes for now.
    [DeviceController.cpp, Registry.h]
2026-03-03 big clean-up of DeviceController and Arduino code TODO: publish events in DeviceController.cpp
    [1_5inch-rgb-oled-module_asm-1110.stp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]
2026-03-05 added mapping for rotation, scale, translate (wip, needs fixes)
    [Registry.h]
2026-03-08 VM-1 Device: animate currently active media slot led
2026-03-09 (WIP) plane switching in ui and mapping-preview
2026-03-26 Mirror Shader; startet with MediaPreview; fixed plane-switching
    [Registry.h]
2026-04-02 Clean-up. Removed CameraPlayer.
2026-04-02 MediaPool updates all filelists (shaders, videos) in background thread.
2026-04-10 Preview scrubbing does not stall video playback anymore.
2026-04-21 Fixed? Clear frame/close pop-up on edit menu change.
2026-04-28 IntSpinBox supports option names. Switching to active media slot on plane change.
2026-04-29 Fixed several issues when moving media slots to a different plane.
2026-04-29 Show staged media slot in CTL. Do not got to SRC main when SHIFT+MediaSlot.
2026-04-30 Fixed freeze frame on plane change with WebcamPlayer. Change CTL display on plane change when slot has entry.
    [Registry.h]
2026-05-01 VM-1 Device: added all analog inputs with a basic filter; bug-fix in i2c receiver-callback; re-writing ButtonState from Enum to Bitmask (wip)
    [VM1Device.ino]
2026-05-01 VM-1-Device ButtonStates as bitmask (wip)
2026-05-01 VM-1 Device rework: using bitmask instead of buttonstate-enum
    [VM1Device.ino]
2026-05-01 fixed ClearSlot on staged MediaSlots
    [Registry.h]
2026-05-01 centralized media button and bank management in registry
2026-05-05 fixed shader controls; added analog inputs (wip) to shaders
    [DeviceController.cpp, Registry.h]
2026-05-05 Added install script for arduino-cli.
2026-05-13 Fixed crash (assigning different type to already used slot).
2026-06-01 further adjustments in DeviceController and KeyboardController
2026-06-09 added PlaybackOperator to UI to get currentVideoPosition
2026-06-11 added NetworkTools.cpp; fixed Blendmode 'add'; added network credentials to WiFi-Panel;
    [Registry.h]
2026-06-11 Added currentPts to VideoInputConfig in Registry.
2026-06-16 fixed 'pause'-function with m_pauseStartTime
    [Registry.h]
2026-06-16 changed currentPts to currentFrame
2026-06-16 changed currentFrame to currentTime (all time values stored in seconds as double); fixed out-point bug; time values in UI are displayed as smpte; added SpinBoxSeconds;
    [Registry.h]
